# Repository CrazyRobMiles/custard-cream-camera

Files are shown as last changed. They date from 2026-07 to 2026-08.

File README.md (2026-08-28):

# Custard Cream Camera

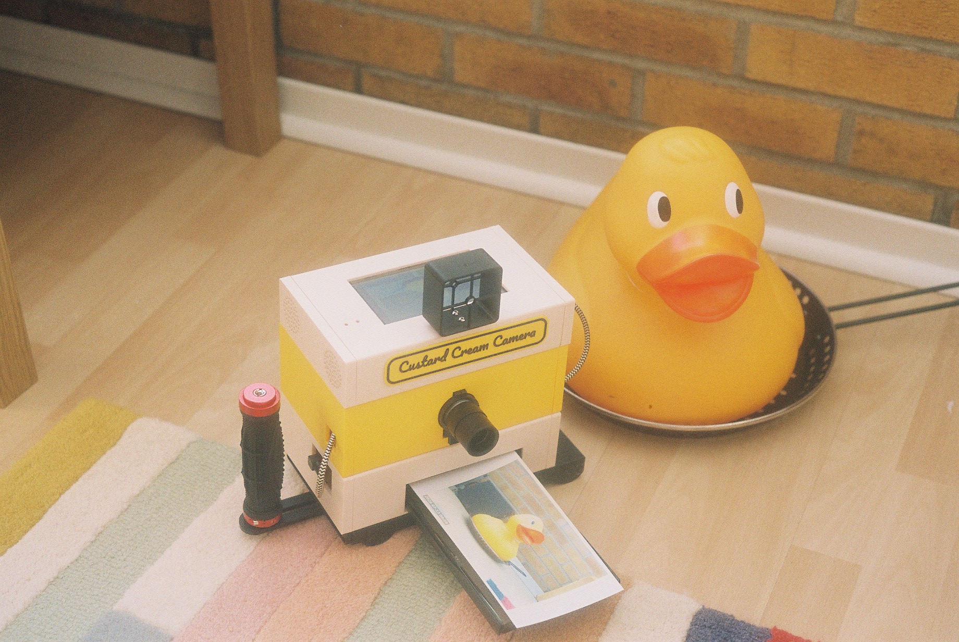
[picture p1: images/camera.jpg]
Image of the camera and a large rubber duck


A camera-and-photo-review appliance for a small touchscreen Raspberry Pi build. Takes pictures (or receives them over FTP from a real camera), lets you review, print, publish, and voice-edit them with AI - and print them on a built-in printer. It can also publish pictures to Flickr, Bluesky, and a self-hosted Custard Cream Camera Server — pick which one from a menu on the Publish button.

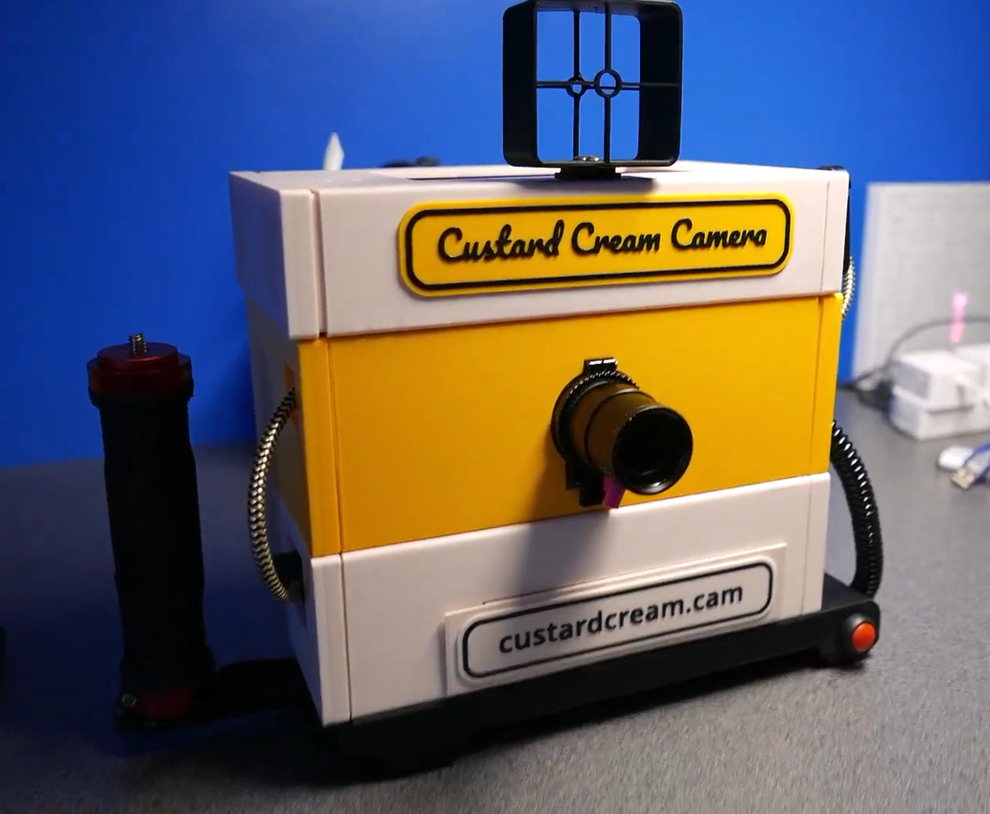
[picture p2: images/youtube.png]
YouTube Screenshot (https://youtu.be/TUCZbDL9_Vs)


To find out more about the camera click on the image above to see a short video.

## Camera configuration

You can use the camera as a camera, or you can use it as an FTP server which other cameras can connect to. All the image storage, processing and printing features are available in this mode. If you are not sure what any of this means, use it in camera mode. 

`settings.json`'s top-level `"mode"` key picks the home screen:

* **`"mode": "camera"`** — a live viewfinder with **Capture**/**Play** modes: take a photo with the on-screen button, a Bluetooth/wired shutter remote, or the keyboard spacebar.
* **`"mode": "ftp"`** — no camera: this device receives JPEGs over FTP (e.g. from a Sony camera's FTP-transfer feature) and is always in Play mode, showing the newest arrival first.
* **`"mode": "camera_ftp"`** — both at once: the live viewfinder/Capture-Play flow of `"camera"` mode, plus the FTP receiver of `"ftp"` mode running in the background. A photo arriving over FTP jumps to the front and interrupts Capture/Play immediately, the same way it does in plain `"ftp"` mode.

Either way, reviewing, printing, publishing, and voice-editing photos already in `captures/` is exactly the same code and behavior — see [Home Screen: Camera Mode vs FTP Mode](docs/home-screen-modes.md).

Inspired by the camera made by [Nikbuild](https://github.com/nickbild/banamera)

## Getting Started

**New device, nothing set up yet?** Follow [Setting Up From Scratch](docs/setup-guide.md) — a
single ordered walkthrough from a bare Raspberry Pi OS install to a running camera, covering system
packages, the venv, `settings.json`, API keys, and every optional feature, in the order you'd
actually do them. Start there rather than the reference list below.

## Reference

Once a device is set up, these cover each feature in more depth than the walkthrough above —
useful when you want to change how something already-configured behaves, or when troubleshooting
something specific.

**Core:**

* [Setting Up the Python Virtual Environment](docs/venv-setup.md) — create, activate, and (if needed) recreate the `venv` this app always runs inside; what differs between camera mode and FTP mode.
* [Running the App](docs/running-the-app.md) — start it from a terminal, or launch it from a desktop icon with no keyboard needed.
* [Storing API Keys on the Device](docs/api-keys.md) — get the Gemini/Flickr/Bluesky/server keys set automatically on every launch, without committing them to git.
* [Display Backends](docs/display-backends.md) — pick between an HDMI touchscreen or a native HDMI display, and configure it in `settings.json`.
* [Home Screen: Camera Mode vs FTP Mode](docs/home-screen-modes.md) — the live viewfinder vs. reviewing FTP-received photos; reviewing/printing/speaking/publishing existing photos works the same either way.

**Camera mode:**

* [Camera Orientation](docs/camera-orientation.md) — fix an upside-down or mirrored viewfinder with `hflip`/`vflip`.
* [Exposure Compensation](docs/exposure-compensation.md) — bias the auto-exposure with on-screen EV+/EV- buttons for backlit or overexposed scenes.
* [Shutter Remotes](docs/shutter-remote.md) — trigger photos and voice edits from a Bluetooth or wired USB-serial remote instead of the touchscreen; either or both can be enabled at once.
* [Audio Output (Shutter Sound)](docs/audio-output.md) — a click sound plays when a photo is taken, configurable and safe to enable even with no audio hardware present.

**FTP mode (and `camera_ftp`):**

* [Receiving Photos over FTP](docs/ftp-setup.md) — configuring the sending camera's FTP-transfer feature to talk to this app, and how uploads get turned into previewable photos.

**Either mode:**

* [Voice-Prompted AI Edits](docs/voice-ai-edits.md) — record a spoken instruction and have Gemini edit the photo.
* [Printing](docs/printing.md) — send photos to CUPS, test the pipeline without wasting paper, and add a watermark/date stamp.
* [Publishing to Flickr](docs/publishing-flickr.md) — one-time OAuth setup, then upload photos straight from the app.
* [Publishing to Bluesky](docs/publishing-bsky.md) — post photos with an app password, no OAuth needed.

**Hardware:**

* [Canon SELPHY CP400 + CUPS](docs/printer-cups-setup.md) — get a CP400 dye-sublimation printer working with CUPS and Gutenprint on Raspberry Pi OS.

## 3D-Printed Case

STL files for the camera's enclosure are in [case/](case/) — print them and snap/screw the lids onto their matching bases:

* **Controller** — `ControllerBase.stl` with `ControllerLid.stl`, `ControllerLeftLid.stl`, and `ControllerSpeakerLid.stl` (vented for the speaker).
* **Battery** — `BatteryBase.stl` with `BatteryLidLeft.stl` and `BatteryLidRight.stl`, plus `batteryHolderLid.stl`.
* **Printer** — `PrinterBase.stl` with `PrinterLidLeft.stl` and `PrinterLidRight.stl`, housing the SELPHY CP400.
* **Handle** — `HandleBase.stl` with `HandleBaseLid.stl`.
* **Paper** — `paperLid.stl` covers the printer's paper tray.

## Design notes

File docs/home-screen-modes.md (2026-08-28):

# Home Screen: Camera Mode vs FTP Mode

`settings.json`'s top-level `"mode"` key (`"camera"`, `"ftp"`, or `"camera_ftp"`) picks which home
screen this app shows. Everything else — reviewing, printing, publishing, and voice-editing photos
already in `captures/` — works identically across all three; only how photos *arrive* differs.

## Camera mode (`"mode": "camera"`)

Live viewfinder with a **Capture** and **Play** mode.

### Capture mode

The default mode: a live viewfinder with **Click** (take a photo) and **Play** (switch to Play
mode) buttons, plus the [exposure compensation](exposure-compensation.md) EV-/EV+ buttons in the
top corners.

### Play mode

Reviews and acts on photos already in `captures/`, one at a time, full screen:

* **Capture** — back to Capture mode (the live viewfinder), without taking a photo.
* **Print** / **Speak or AI Edit** / **Publish** — act immediately on whichever photo is currently
  shown, no separate "choose, then act" step. The AI-edit button's behavior depends on
  `"ai_edit"` in settings.json: by default (`"input_method": "voice"`) it's **Speak**, hold-to-talk
  — press to record an editing instruction, release to send it; with `"input_method": "keyboard"`
  it's **AI Edit**, a normal tap that opens a grid of preset prompts plus a custom on-screen-keyboard
  option instead. Setting `"ai_edit.enabled"` to `false` removes this button entirely. **Publish**
  opens a menu of every *enabled* destination (Flickr, Bluesky, Custard Cream Server, ...) — tap one
  to send this photo there and return here, with a "Published to \<name\>!" confirmation naming
  which one; publishing to more than one destination means pressing **Publish** again afterwards and
  picking another. If only one destination is enabled, Publish skips the menu and sends straight to
  it. See [Voice-Prompted AI Edits](voice-ai-edits.md), [Printing](printing.md), and
  [Publishing to Flickr](publishing-flickr.md) for what each of those actually does.
* **`<`** / **`>`** (small buttons on the left/right screen edges) — step to the previous/next
  photo one at a time, newest-first.
* **Page** (top-right corner) — opens a 3×3 grid of the current page of 9 photos; tapping a
  thumbnail makes it the current selection and returns to the single-photo view. **Left**/**Right**
  in the grid page through older/newer groups of 9; **Back** returns to the single-photo view
  without changing the selection.
* **Stop** (top-left corner) — exits the app cleanly. This is the only on-screen way to quit, for
  when it's launched from the [desktop icon](running-the-app.md) with no keyboard or window chrome
  available.

Entering Play mode (via the **Play** button, from anywhere) always lands on the most recently taken
photo - it re-scans `captures/` fresh each time rather than remembering a stale position from last
visit. An AI edit or a fresh **Click** while reviewing similarly become the new current selection,
the same as if you'd just taken them.

There's no on-screen quit button in Capture mode — switch to Play mode and use **Stop**, or press
keyboard `q` in the terminal, or (on the HDMI backends) Escape / close the window.

### The physical shutter remote and keyboard spacebar

The [Bluetooth shutter remote](shutter-remote.md)'s photo key and the keyboard spacebar behave
differently depending on mode:

* In **Capture mode**, they take a photo immediately, same as **Click**.
* In **Play mode**, they switch back to Capture mode *without* taking a photo — pressing the
  physical shutter while reviewing old photos shouldn't blindly capture whatever the camera happens
  to be pointed at; it just gets you back to the viewfinder to compose deliberately.

The remote's speak key is unaffected by mode — it always bypasses Play mode entirely and acts
immediately on a fresh capture, since requiring on-screen navigation would defeat the point of a
physical, look-free trigger.

## FTP mode (`"mode": "ftp"`)

There's no camera, so there's no Capture mode to switch away from - this is always Play mode. The
app starts on a "Waiting for photos..." placeholder and shows the most recent photo full-screen as
soon as one arrives (see [Receiving Photos over FTP](ftp-setup.md)):

* **Print** / **Speak** / **Publish** / **`<`** / **`>`** / **Page** / **Stop** — same buttons and
  behavior as camera mode's Play mode above, just with no **Capture** button (there's no other mode
  to switch to).

### When a new photo arrives

A newly-received photo always jumps to the front and becomes the current selection - the same way a
fresh AI edit does. If it arrives while you're stepping through older photos, or while a
Publish/Print/AI-edit is quietly working in the background, it interrupts that and shows the new
one right away (any publish/print/edit already in flight keeps working on the photo it started with
- only the screen moves on). If it arrives while a full-screen banner or review/keyboard screen has
temporarily taken over (a "Published!"/print-result banner, the QR-code screen, or the
Send/Reject/Edit review from [Voice-Prompted AI Edits](voice-ai-edits.md)), it's picked up as soon
as that screen closes rather than interrupting it mid-way.

Restarting the app rescans `captures/` for anything already there (e.g. left over from before a
restart) and shows the newest, the same as the first-arrival case.

There's no live viewfinder, no exposure compensation, and no shutter button in this mode - it never
takes a photo itself, only receives ones already taken.

## Camera + FTP mode (`"mode": "camera_ftp"`)

Both of the above at once: the live viewfinder and Capture/Play flow from Camera mode, plus the FTP
receiver from FTP mode running in the background the whole time - see
[Receiving Photos over FTP](ftp-setup.md) for configuring the sending camera's side. The app starts
in Capture mode, same as plain Camera mode.

A photo arriving over FTP behaves exactly as described in
[When a new photo arrives](#when-a-new-photo-arrives) above - it jumps to the front and interrupts
whatever's on screen (Capture mode's live viewfinder included), the same way it would in plain FTP
mode. The live viewfinder itself keeps running in the background while that photo is shown; press
**Capture** to go back to it.

This is useful when you want the device's own camera and an external camera's FTP-transfer feature
(e.g. a Sony body) both feeding the same `captures/` folder and review flow, rather than choosing
one or the other.

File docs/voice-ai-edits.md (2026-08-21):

# Voice-Prompted AI Edits

How you provide the editing instruction is controlled by `"input_method"` under `"ai_edit"` in
[settings.json](../settings.json.example) — `"voice"` (the default, described first below) or
`"keyboard"` (preset prompts plus a custom on-screen keyboard entry, see
[Keyboard/Preset Input](#keyboardpreset-input) further down). Setting `"ai_edit.enabled"` to
`false` removes AI editing entirely — no button in Play mode, and (camera mode) no shutter-remote
speak-key binding either — useful for a device that only needs to receive/print/publish photos,
e.g. a low-spec Pi Zero-class image receiver.

## Voice input (`ai_edit.input_method`: `"voice"`, the default)

In Play mode (see [Home Screen: Camera Mode vs FTP Mode](home-screen-modes.md)), hold **Speak** (or, in camera mode, use the shutter remote's speak key, which works from any mode), say an editing instruction (e.g. "make it look like a watercolor painting"), and release. The app transcribes what you said, then shows you the transcript with three options before anything is sent anywhere for editing:

* **Send** — sends it, with the currently displayed image, to Google's Gemini ("Nano Banana") image model for editing.
* **Reject** — discards it. Nothing is sent for editing; you're back where you started.
* **Edit** — opens an on-screen keyboard to correct the text (misheard words, added detail, etc.), then returns to this same Send/Reject/Edit screen with the corrected text.

This review step exists because speech recognition isn't perfect, and a misheard instruction sent straight to an image-editing model wastes a request (and, depending on your Gemini plan, a quota unit) on a result you never wanted. Once sent, the result is saved to `captures/` as `ai_<timestamp>.jpg`, shown on screen for a few seconds, and becomes the new current selection. Image editing always goes through Gemini; the app stays responsive while it's working since the network calls run on a background thread.

Transcription (turning your speech into the text prompt) is a **pluggable backend**, selected via `"transcribe_provider"` under `"custard_cream"` in [settings.json](../settings.json.example) — this setting only matters when `"ai_edit.input_method"` is `"voice"`:

- **`"vosk"` (the shipped default)** — runs entirely on the device via a local [Vosk](https://alphacephei.com/vosk/) model, no network round-trip. Since it recognises speech live, the transcript is displayed on screen as you talk, updating word by word while **Speak** is still held. Implemented in [lib/transcription/vosk_transcriber.py](../lib/transcription/vosk_transcriber.py).
- **`"gemini"`** — sends the whole recording to Gemini once you release **Speak**. No live text — just the "Recording... release to send" banner until it's done. Implemented in [lib/transcription/gemini_transcriber.py](../lib/transcription/gemini_transcriber.py).

Both backends implement the same interface ([lib/transcription/base.py](../lib/transcription/base.py)), selected by [lib/transcription/__init__.py](../lib/transcription/__init__.py)'s `create_transcriber()` — the same plugin pattern used for [publishers](../lib/publishers/) and [displays](../lib/displays/). Image editing itself is unaffected by this choice and stays in [lib/NanoBananaClient.py](../lib/NanoBananaClient.py). The whole flow (`start_voice_prompt()`/`finish_voice_prompt()`/`review_ai_prompt()`/`run_ai_edit()`/...) lives in [custard_cream_camera.py](../custard_cream_camera.py) — the fresh-capture branch it falls back to only matters in camera mode, since an FTP-mode device never captures a photo itself.

On a lower-powered device (e.g. a Pi Zero W 2 running in FTP mode), consider `"vosk"` over `"gemini"` for transcription if the network connection is unreliable, since it needs no round-trip at all - though the image-edit step itself always needs Gemini regardless.

## Keyboard/Preset Input

Set `"ai_edit.input_method"` to `"keyboard"` for a device with no microphone, or where speech
recognition simply isn't wanted (e.g. a low-spec Pi Zero-class image receiver/printer, where a
local Vosk model is too much for the hardware - see below). The Play-mode button becomes **AI
Edit** (a normal tap, not hold-to-talk) instead of **Speak**:

* Tapping it shows a grid of the prompts configured under `"ai_edit.presets"` in settings.json (any
  number, not just four - laid out two per row), plus **Custom...** and **Back**.
* Picking a preset, or **Custom...** (which opens the same on-screen keyboard **Edit** uses in the
  voice flow above, starting blank), lands on the same Send/Reject/Edit confirm screen described
  above - so a preset or typed prompt can still be tweaked or rejected before it's sent to Gemini.
* **Back** returns to Play mode without choosing anything.

Crucially, no transcriber is created at all in this mode (nor when `"ai_edit.enabled"` is
`false`): `"transcribe_provider"`/`"vosk"` in settings.json are simply not read, the `vosk` package
is never imported, and no Vosk model is loaded into memory - important on something like a Pi Zero,
where even a "small" ~40MB model is a real cost you don't want to pay if voice input is never used.
In camera mode, the shutter remote's speak key is also left unbound in this case, since it exists
purely to drive hold-to-talk.

## Setup

Steps 1 and 3 (the Gemini API key) apply regardless of `"ai_edit.input_method"`, since image
editing always goes through Gemini. Steps 2, 4, and 5 only matter for `"input_method": "voice"` —
skip them entirely for `"keyboard"` (or `"ai_edit.enabled": false`).

1. **Get a Gemini API key.** Go to [aistudio.google.com/apikey](https://aistudio.google.com/apikey), sign in with a Google account, and create a key. This is needed for image editing regardless of transcription backend, and for transcription itself if you use `"gemini"`.

2. **Make sure the SDKs are installed.** `google-genai` is already in [requirements.txt](../requirements.txt), pulled in by the normal `pip install -r requirements.txt` venv setup. `vosk` is kept in its own [requirements-vosk.txt](../requirements-vosk.txt) instead (see [Setting Up the Python Virtual Environment](venv-setup.md)), since it's a real install/memory cost not worth paying on a device that never uses voice input — install it with `pip install -r requirements-vosk.txt` if you're using `"vosk"` as the provider.

3. **Set the API key as an environment variable.** `NanoBananaClient.py` reads it from `GOOGLE_API_KEY` by default (the variable name is itself configurable via `"api_key_env"` under `"custard_cream"` in settings.json) — deliberately *not* stored in `settings.json`, since that file is checked into git. For a quick one-off test from a terminal:
   ```bash
   export GOOGLE_API_KEY="your-api-key"
   ```
   For it to be set automatically every time the app runs (including from the desktop icon, with no terminal involved) see [Storing API Keys on the Device](api-keys.md).

4. **If using Vosk, download a model.** See [Installing Vosk](venv-setup.md#installing-vosk-local-speech-recognition) for the exact download/unzip commands and a one-liner to verify it loads. The default settings expect `vosk-model-small-en-us-0.15` (~40MB) unzipped to `models/vosk-model-small-en-us-0.15`, matching `"custard_cream.vosk.model_path"` in settings.json — adjust that setting if you use a different model or location. **This is loaded once at app startup** (not on first Speak press, to avoid a delay on first use) — a missing or wrong `model_path` will fail app startup entirely, not just the Speak feature, so get this right before relying on Vosk as the active provider.

5. **Check the microphone.** Both backends need `arecord` (part of `alsa-utils`, normally already installed on Raspberry Pi OS — `sudo apt install alsa-utils` if not). Confirm it works standalone first:
   ```bash
   arecord -f S16_LE -r 16000 -c 1 -d 3 test.wav && aplay test.wav
   ```
   If you have multiple audio devices, set `"device"` under `"custard_cream"` in settings.json to the right ALSA device name (`arecord -l` lists them) — it's `null` by default, which uses the system default input. This is shared by both transcription backends, since it's a property of the physical mic, not the transcriber.

6. **Test it.** Play mode has no option to take a fresh photo, so make sure at least one photo exists first — in camera mode, press **Click** (in Capture mode); in FTP mode, [receive a photo over FTP](ftp-setup.md). Then: hold **Speak**, say something like "make it look like a watercolor painting" (if using Vosk, watch the recognised text build up on screen as you talk), and release. The edited image should then appear on screen and save to `captures/ai_<timestamp>.jpg`.

Recording length and the result's on-screen hold time are also configurable under `"custard_cream"` in settings.json. The Gemini model IDs (`transcribe_model`, `edit_model`) may need adjusting as Google's model naming evolves — check the current names in the [Gemini API docs](https://ai.google.dev/gemini-api/docs/models) if editing (or Gemini-backend transcription) fails with a "model not found" style error.

## Diagnostics

Progress is shown on screen as well as logged. While a request is in flight, the banner that would otherwise just say "Processing..." instead shows what's actually happening: "Transcribing...", then (once you've reviewed and sent the prompt) "Sending image for processing...", then "Received result, saving..." — the same on-screen-diagnostics idea used for [printing](printing.md), applied to this workflow.

Every stage also prints a `Speak: ...` line to the terminal (or `custard_cream_camera.log`), so a stuck or failed edit can be narrowed down to exactly where it stopped: recording start/stop, transcription (whichever backend is active) and its result, whether the prompt was sent/rejected at the review step, the request sent for image editing, and the response received (including any text the model returned instead of an image, e.g. a safety refusal — normally invisible on screen, since the caller only ever sees `None`).

Requests to Gemini time out after `"timeout_seconds"` (default `30`) under `"custard_cream"` in settings.json — without this, a stalled connection (flaky wifi, a network path that silently drops packets) would hang indefinitely with no error and no diagnostic output at all. This only applies to work that actually goes over the network: image editing always, and transcription only when `"transcribe_provider"` is `"gemini"` — Vosk transcription is local and isn't affected by connectivity at all. If a Gemini-backed request hangs repeatedly even with a normally-reliable connection, try raising `"timeout_seconds"` in case it's just Gemini being slow rather than the connection actually stalling.

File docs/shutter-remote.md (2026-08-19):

# Shutter Remotes

The app supports three independent physical shutter remotes — a Bluetooth one, a wired USB-serial one, and a plain GPIO push-button — each with its own `"enabled"` flag in [settings.json](../settings.json.example), so any or all can be active at once.

## Bluetooth Shutter Remote

Cheap Bluetooth camera remotes don't have a real "pairing mode" — they just have two buttons/positions (labelled iOS/Android or similar) that each send a different key, since iOS and Android camera apps historically listened for different shortcuts. [shutter_remote.py](../shutter_remote.py) listens for both directly at the input-device level (via `evdev`), independent of which window has focus:

* **iOS** button → Volume Up (`KEY_VOLUMEUP`) → takes a photo in [Capture mode](home-screen-modes.md), the same action as the **Click** button - or, if you're currently in Play mode reviewing photos, switches back to Capture mode without taking a photo.
* **Android** button → Enter (`KEY_ENTER`) → hold-to-talk, the same as **Play** mode's **Speak** button: pressing starts recording, releasing sends it. Unlike the photo key, this works from any mode - it always acts on a fresh capture, bypassing Play mode entirely. This relies on the remote sending a genuine press-then-release pair for a physical hold, which is normal HID keyboard behavior, but worth confirming for your specific unit (see below).

To enable it:

1. Set `"shutter_remote": {"enabled": true}` in [settings.json](../settings.json.example).
2. Make sure your user can read input devices: `sudo usermod -aG input $USER`, then log out and back in (or reboot) for group membership to take effect.

The Volume Up mapping is easy to confirm: pressing the iOS button should show your desktop's volume OSD. The Enter mapping is a best guess for "Android mode" on these remotes — if it doesn't trigger recording, confirm the actual key it sends (see below), and set `"photo_key"`/`"speak_key"` in `settings.json` to match (either can be set to `null` to disable that mapping without disabling the other).

### Automatic device discovery

`"device_name"` normally doesn't need to be set at all. `shutter_remote.py` already knows exactly which keys it cares about (`photo_key`/`speak_key`), so with `"device_name": null` it auto-selects any connected input device that reports supporting one of those keys — asking each device "can you send `KEY_VOLUMEUP`/`KEY_ENTER`?" rather than needing to be told a product name up front. This is also what makes `"grab": true` safe by default: it can only ever grab a device that actually reports one of those two keys, never your touchscreen, mouse, or keyboard, since none of those report `KEY_VOLUMEUP`/`KEY_ENTER` as a capability.

Startup then prints just the auto-selected devices, e.g.:
```
ShutterRemote: listening on AB Shutter3        Keyboard, AB Shutter3        Consumer Control
```
Bluetooth "combo" remotes like this commonly register as *two* separate logical devices, since Enter and Volume Up/Down live on different HID pages (`Keyboard` vs `Consumer Control`) — both get auto-selected independently since each reports one of the two keys.

**Caveat:** capability matching can occasionally over-match — e.g. many USB audio adapters/microphones expose a "media control" HID interface reporting `KEY_VOLUMEUP`/`KEY_VOLUMEDOWN`/`KEY_MUTE` even without physical buttons, purely as part of the USB Audio Class spec, so one could get auto-selected too (and grabbed, if `"grab": true"`, though this shouldn't affect its actual audio capture - that's a separate USB interface). Usually harmless, since it'd only matter if that device ever emits a real `KEY_VOLUMEUP` event, but if something unrelated seems to be triggering captures, or you'd rather target the remote precisely, set `"device_name"` to its name (visible in the startup log above, or via `evtest`) to bypass capability matching entirely for an explicit name match instead:
```bash
sudo apt install evtest
sudo evtest   # pick your remote from the list, press a button, read the KEY_ name and device name
```

**Not being detected?** `shutter_remote.py` retries device discovery every second (Bluetooth remotes routinely disconnect between presses to save battery, and may not even be connected yet when the app starts), so it should pick the remote up on its own within a second or two of it reconnecting. If it still doesn't, try power-cycling the remote — a stale/half-open Bluetooth connection from a previous session is a common cause and a fresh reconnect usually clears it.

**Was working, then stopped reconnecting entirely?** `shutter_remote.py` only watches for input devices the OS has already connected — it doesn't drive Bluetooth pairing/reconnection itself, so if `bluetoothd` stops auto-reconnecting to the remote, there's nothing for it to find no matter how long it retries. Check:
```bash
bluetoothctl devices          # find the remote's MAC address
bluetoothctl info <MAC>       # check Paired/Connected/Trusted
```
If `Paired: yes` but `Connected: no`, and `Trusted: no`, that's very likely the cause — an untrusted paired device doesn't get automatically reconnected by `bluetoothd` the same way a trusted one does, so once it disconnects (its normal power-saving behavior) it just stays disconnected until something explicitly reconnects it. Fix it with:
```bash
bluetoothctl trust <MAC>
```
which should make it reconnect immediately and keep auto-reconnecting from then on.

## Wired (USB Serial) Shutter Remote

For a simple homemade remote connected over USB serial and sending the word `click` (newline-terminated) each time its button is pressed. Implemented in [serial_shutter_remote.py](../serial_shutter_remote.py), it's much simpler than the Bluetooth remote above: one button, one action - it always takes a photo (the same event as the Bluetooth remote's `photo_key`), the same as pressing **Click** in Capture mode or, if you're currently in Play mode, switching back to Capture mode without taking a photo. It doesn't have a Speak/hold-to-talk equivalent.

To enable it:

1. Plug the remote in and find its device path: `ls /dev/ttyUSB* /dev/ttyACM*` (USB-serial adapters usually show up as one or the other, depending on the chip they use).
2. Set `"serial_remote"` in [settings.json](../settings.json.example):
   ```json
   "serial_remote": {
       "enabled": true,
       "port": "/dev/ttyUSB0",
       "baud_rate": 9600
   }
   ```
   `"baud_rate"` must match whatever the remote's firmware is actually configured to send at - 9600 is a common default, but check your specific device.
3. Make sure your user can access serial ports: `sudo usermod -aG dialout $USER`, then log out and back in (or reboot) for group membership to take effect.

This remote and the other two are fully independent - any combination can be `"enabled": true` at once, each triggering the same photo action.

**Not being detected / nothing happens on click?** Like the Bluetooth remote, `serial_shutter_remote.py` retries opening the port every second if it's missing (unplugged, not yet enumerated at boot), so it should pick the remote up within a second or two of being plugged in - check the console/log for a `SerialShutterRemote: listening on ...` line to confirm it connected. If it connects but clicks don't register, confirm what the remote is actually sending, e.g.:
```bash
screen /dev/ttyUSB0 9600
```
(press the remote's button and confirm you see `click` printed; `Ctrl-A` `k` `y` to exit `screen`) - a mismatched baud rate typically shows up as garbled text rather than silence.

## GPIO Shutter Remote

For a switch wired directly to a GPIO pin on the Pi - no microcontroller/USB adapter needed. Implemented in [gpio_shutter_remote.py](../gpio_shutter_remote.py) using [gpiozero](https://gpiozero.readthedocs.io/), which handles debouncing itself, so the wiring can be as simple as a switch between the GPIO pin and ground.

Like the serial remote, it's one button, one action - it always takes a photo, the same as pressing **Click** in Capture mode or, if you're currently in Play mode, switching back to Capture mode without taking a photo.

To enable it, set `"gpio_remote"` in [settings.json](../settings.json.example):
```json
"gpio_remote": {
    "enabled": true,
    "pin": 26,
    "active_low": true
}
```
* `"pin"` is the BCM GPIO number (not the physical header pin number) the switch is wired to.
* `"active_low"` should be `true` if the switch connects the pin to ground when pressed (the pin idles high via the Pi's internal pull-up resistor, and reads low when pressed) - this is the simplest wiring, needing nothing but a switch and two wires. Set it to `false` if the switch instead connects the pin to 3.3V when pressed (the pin idles low via the Pi's internal pull-down resistor, and reads high when pressed).

This remote and the other two are fully independent - any combination can be `"enabled": true` at once, each triggering the same photo action.

**Nothing happens on press?** Check the console/log for a `GpioShutterRemote: listening on GPIO<pin> (active low/high)` line at startup to confirm the pin opened - if it prints a "could not open" error instead, another process may already be using that pin, or the pin number may not exist on your Pi model. If it opened fine but presses don't register, double check `"active_low"` matches your wiring - a switch wired to ground with `"active_low": false` (or vice versa) will just look like the button is permanently held (or never pressed) rather than causing an obvious error.

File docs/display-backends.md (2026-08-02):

# Display Backends

`custard_cream_camera.py` renders through a pluggable display layer in [lib/displays/](../lib/displays/). One backend is provided, for devices with a native HDMI display — a SPI panel backend (`ili9486`) used to be supported but was dropped: its framerate was too low to manually focus the camera image, making it non-viable as a platform regardless of anything else. A dedicated fullscreen SDL/pygame backend (`hdmi-pygame`) was also dropped: `hdmi-desktop` turned out to be fast enough on its own, so there was no need to carry the extra SDL video-driver dependency and setup burden.

* `hdmi-desktop` — a plain window via Tkinter, using the mouse for touch input ([lib/displays/hdmi_desktop_display.py](../lib/displays/hdmi_desktop_display.py)). No fullscreen mode-switching or video driver selection — it just opens an ordinary window through whatever windowing system the desktop is already using, the same as any other desktop app.

Select the backend and tune its options in [settings.json](../settings.json.example):

```json
{
    "display": {
        "type": "hdmi-desktop",
        "width": 800,
        "height": 480
    }
}
```

`hdmi-desktop` needs Tkinter, which on Raspberry Pi OS / Debian is a system package, not a pip one:

```bash
sudo apt install python3-tk
```

## `width`/`height` — the logical canvas size

Every screen (menus, the viewfinder or current photo, the on-screen keyboard) is drawn against a logical canvas of `width` x `height`, then scaled up to fill whatever the real window/output size is. Defaults to `480`x`320` if omitted, matching the size this app originally shipped with.

A bigger canvas gives more room for on-screen text and controls (e.g. the AI-prompt keyboard, see [Voice-Prompted AI Edits](voice-ai-edits.md)) at the cost of more pixels to draw per frame - worth watching on a lower-powered device (e.g. a Pi Zero W 2), which has much less headroom than a full-size Pi. If a larger size causes worse frame rates on your hardware, drop `width`/`height` back down (or remove them entirely to fall back to `480`x`320`) — no code change needed either way. Every layout in the app computes itself from these values at runtime rather than assuming a fixed size, so any resolution should work.

## `DISPLAY`/`XDG_RUNTIME_DIR` not set

Both HDMI backends need `DISPLAY` (and ideally `XDG_RUNTIME_DIR`) set to reach the desktop session — normally automatic when logged into the Pi's own desktop, but **not** when launched from a plain SSH shell or a remote-dev tool's integrated terminal (e.g. VS Code Remote-SSH), which don't inherit those variables. Activating the Python venv doesn't set them either (it only touches `PATH`), so this can bite regardless of venv use.

`lib/displays/__init__.py` fills in a best-effort default for either one if it's missing — it looks for a real X11 socket under `/tmp/.X11-unix` and a real `/run/user/<uid>` directory, and only sets the variable if it finds one (it won't invent a display that doesn't actually exist), printing what it defaulted to. This should cover the common case of a single desktop session on `:0` without you needing to `export` anything by hand. If it still can't find one — e.g. no desktop session is running at all — the underlying error will still surface, since at that point there's genuinely nothing to connect to.

## Touch/clicks stop responding, but the cursor still moves

If the touchscreen (or mouse) can move the cursor around but clicks don't register anywhere, the likely cause is a modal dialog left open somewhere behind the app, silently eating every click because it's waiting for you to click its own OK/Cancel first. This is easy to miss since the app is fullscreen and the dialog is hidden underneath it.

The known trigger is the one-time Flickr `setup_flickr_auth.py` script (see [Publishing to Flickr](publishing-flickr.md)): if a browser is opened directly on the Pi's own desktop for the OAuth step, it can prompt for a keyring/password dialog to store the saved login, and that dialog stays open — and stays modal — even after the browser flow is done. Dismissing it (even indirectly, e.g. by unplugging a keyboard that happened to also close it) immediately restores clicking. Nothing this app itself does should pop up a dialog, so as long as the desktop is clean before launching it, this shouldn't come up — but if clicks ever mysteriously stop working, check for a stray dialog window before assuming it's a display/touch driver problem.

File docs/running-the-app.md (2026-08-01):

# Running the App

## From a Terminal

Once the virtual environment has been activated:

```bash
python custard_cream_camera.py
```

## From a Desktop Icon

[run_custard_cream_camera.sh](../run_custard_cream_camera.sh) and [custard-cream-camera.desktop](../custard-cream-camera.desktop) let you launch the app by double-clicking an icon instead of typing commands in a terminal. The script finds its own location automatically and activates `venv` if one exists next to it. `custard-cream-camera.desktop` ships with `Terminal=false`, so no terminal window appears — if `custard_cream_camera.py` exits with an error, the output goes to `custard_cream_camera.log` next to the script instead of a window you'd need a keyboard to dismiss. Set `Terminal=true` if you'd rather see a terminal window on launch (it will then keep it open on error so you can read what went wrong, instead of logging to a file).

To install it:

1. Edit `Exec=` in `custard-cream-camera.desktop` if this repo isn't cloned at `/home/rob/custard-cream-camera`.
2. Copy the `.desktop` file to your desktop and/or application menu:
   ```bash
   cp custard-cream-camera.desktop ~/Desktop/
   cp custard-cream-camera.desktop ~/.local/share/applications/   # to also show it in the app menu
   ```
3. Make sure both `run_custard_cream_camera.sh` and the `.desktop` file are executable — git doesn't reliably preserve the executable bit across clones, so a fresh clone can silently lack it, which shows up as the icon failing to launch (PCManFM reports this as "Invalid desktop entry file", which is misleading — the underlying cause is `Permission denied` running the script):
   ```bash
   chmod +x ~/custard-cream-camera/run_custard_cream_camera.sh
   chmod +x ~/Desktop/custard-cream-camera.desktop
   ```
   Most file managers also treat a newly-placed `.desktop` file as untrusted the first time — right-click the icon and choose "Allow Launching" / "Trust" (wording varies by desktop environment).
   On Raspberry Pi OS's default file manager, PCManFM, double-clicking instead pops up an "Execute / Execute in Terminal / Open / Cancel" menu every time, even once the file is executable - this isn't the same "untrusted" mechanism GNOME/Nautilus uses (so `gio set metadata::trusted` has no effect here), it's a PCManFM-only setting. Fix it via **File Manager → Edit → Preferences → General → "Don't ask options on launch executable file"**. This writes `quick_exec=1` to PCManFM's own config file - editing that file directly isn't a reliable alternative, since it may not exist yet until PCManFM has been opened/configured at least once. Note this is a global toggle: it suppresses the confirmation for any executable double-clicked on the desktop, not just this icon.

## What you'll see on launch

Depends on `settings.json`'s `"mode"` — see [Home Screen: Camera Mode vs FTP Mode](home-screen-modes.md):

* **Camera mode** — a live viewfinder with **Click**/**Play** buttons.
* **FTP mode** — no camera, so no viewfinder: it starts on a "Waiting for photos..." placeholder and switches to showing the newest received photo as soon as one arrives over FTP. See [Receiving Photos over FTP](ftp-setup.md) for configuring the camera side.

## A browser/keyring password dialog appears when the app closes

`custard_cream_camera.py` never opens a browser itself - if one appears (often along with a prompt to unlock/create a login keyring) right as the app exits, it's almost always a leftover browser window from the one-time `setup_flickr_auth.py` step (see [Publishing to Flickr](publishing-flickr.md)), still sitting open behind the fullscreen app the whole time it was running. Closing the app's fullscreen window just reveals what was underneath, it isn't spawning anything new.

Close the stray browser (`pkill chromium`, or whatever browser you used) to clear it. To stop it happening again:

* Run `setup_flickr_auth.py`'s browser step on a different device (phone, laptop) rather than this Pi's own desktop, and close that browser window once you've pasted the verification code back into the terminal.
* If you don't want passwords persisted on the Pi at all, turn off Chromium's password saving so it has nothing to ask the keyring to store: address bar → `chrome://settings/passwords` → toggle off **"Offer to save passwords"** (or via the **⋮** menu → Settings → Autofill and passwords → Password Manager if typing the URL doesn't work). You can also launch Chromium with `--password-store=basic` to bypass the OS keyring entirely.

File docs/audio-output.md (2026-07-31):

# Audio Output (Shutter Sound)

Taking a photo (via the **Click** button, the [shutter remote](shutter-remote.md), or the spacebar) plays a short click sound in addition to the white screen flash, via `aplay`. This is implemented as a fire-and-forget call in `play_sound()` in [custard_cream_camera.py](../custard_cream_camera.py) - it never blocks on the sound finishing, and never raises if playback fails, so a missing or misconfigured audio device just means silence instead of a broken shutter button. This makes it safe to leave enabled even on a device with no audio hardware at all.

Configurable under `"audio_output"` in [settings.json](../settings.json.example):

```json
"audio_output": {
    "enabled": true,
    "device": null,
    "shutter_sound": "assets/audio/shutter.wav"
}
```

* `"enabled"` — set `false` to disable the sound entirely (the screen flash still happens either way).
* `"device"` — an explicit ALSA device string (e.g. `"plughw:3,0"`), passed to `aplay -D`. Leave `null` to use ALSA's `default` device.
* `"shutter_sound"` — path to a `.wav` file, relative to the repo root. The one shipped in [assets/audio/](../assets/audio/) is a short synthesized click generated with Python's stdlib `wave` module (not a real recording) - swap in your own `.wav` file here if you'd like a different sound.

## Finding the right output device

```bash
aplay -L
```
lists everything ALSA can currently see. On a plain HDMI/analog setup this is normally enough for `"device": null` to just work.

If you want to route through a Bluetooth speaker on modern Raspberry Pi OS (Bookworm and later), audio is managed by **PipeWire** + **WirePlumber**, not the ALSA `default` device directly - `wpctl status` will show the speaker under "Sinks" once paired and connected, even though it won't yet appear in `aplay -L`. `aplay` (a plain ALSA client) can only reach it once the ALSA→PipeWire bridge is installed:
```bash
sudo apt install pipewire-alsa
```
After that, `aplay -L` should show a `pipewire` entry, which either becomes the new ALSA default automatically or can be set explicitly via `"device": "pipewire"`.

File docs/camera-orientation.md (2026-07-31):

# Camera Orientation

If the live viewfinder (or captured photos) comes out flipped or upside down - typically because the HQ camera sensor ended up mounted rotated in the enclosure - correct it with `"hflip"`/`"vflip"` under `"camera"` in [settings.json](../settings.json.example), rather than physically remounting the sensor or rotating images in software after the fact:

```json
"camera": {
    "hflip": true,
    "vflip": true
}
```

Both `true` (the default in this repo's `settings.json`) corrects a sensor mounted rotated 180 degrees; use just one of the two if your image is mirrored on a single axis instead. This is applied once, in the camera's own capture pipeline via `libcamera`'s `Transform`, so it covers the viewfinder, saved photos, and whatever gets sent off for AI editing - not something each part of the app has to individually work around.

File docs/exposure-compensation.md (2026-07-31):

# Exposure Compensation

Small "EV-"/"EV+" buttons in the top corners of the live viewfinder let you bias the exposure by a number of EV stops - enough to rescue a backlit subject (positive EV) or an overexposed bright scene (negative EV). At EV 0 the camera runs fully auto-exposed as normal. Moving off EV 0 snapshots the auto-exposure algorithm's current shutter speed/gain as a baseline, disables auto-exposure, and explicitly sets a shutter speed scaled by `2^EV` from that baseline - every further +/- press rescales from the same baseline rather than the live (now manually-overridden) reading, so repeated presses give a clean, repeatable offset instead of drifting. Auto-exposure resumes as soon as you return to EV 0.

(An earlier version tried to do this via libcamera's `ExposureValue` control, which is meant to bias AE without disabling it - it turned out to be a no-op on this camera/tuning stack, silently accepted but with no effect on the actual shutter speed, hence the explicit snapshot-and-scale approach instead.)

The current EV offset, plus the actual metered shutter speed and gain, are shown at the top of the viewfinder at all times - useful for confirming the buttons are having a real effect, not just changing the on-screen number. The EV offset resets to the default each time the app starts (it isn't saved back to `settings.json`).

Range and step are configurable under `"exposure"` in [settings.json](../settings.json.example):

```json
"exposure": {
    "default": 0.0,
    "step": 0.5,
    "min": -2.0,
    "max": 2.0
}
```

This is separate from the manual aperture ring on the lens itself - that's a physical adjustment outside the app's control, and exposure compensation on top of it works the same way it would on any camera with an auto-exposure mode.

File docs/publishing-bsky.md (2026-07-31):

# Publishing to Bluesky

The **Publish** button (see [Home Screen: Camera Mode vs FTP Mode](home-screen-modes.md)) opens a menu of every configured destination — tapping **Bluesky** there posts the currently displayed photo, using the [atproto](https://atproto.blue) package. This is a sibling of [flickr_publisher.py](../lib/publishers/flickr_publisher.py) in the same pluggable [lib/publishers/](../lib/publishers/) layer — see [Publishing to Flickr](publishing-flickr.md) for the general shape.

## One-time setup

Unlike Flickr, Bluesky doesn't need a browser-based OAuth flow at all — just a handle and an **app password**:

1. Go to [bsky.app/settings/app-passwords](https://bsky.app/settings/app-passwords) while logged into your Bluesky account and create a new app password. Use this, never your real account password — this app stores it in an environment variable, and an app password can be revoked independently if it's ever compromised.
2. Set your handle and the app password as environment variables (same reasoning as the other API keys — never stored in `settings.json`, which is checked into git):
   ```bash
   export BSKY_HANDLE="your-handle.bsky.social"
   export BSKY_APP_PASSWORD="your-bsky-app-password"
   ```

For these to be set automatically every time the app runs (including from the desktop icon), see [Storing API Keys on the Device](api-keys.md) — same as the other keys.

## Configuration

```json
"publish": {
    "bsky": {
        "enabled": true,
        "handle_env": "BSKY_HANDLE",
        "app_password_env": "BSKY_APP_PASSWORD",
        "text": "",
        "alt_text": ""
    }
}
```

* `"enabled"` — set to `false` to take Bluesky out of the Publish menu without deleting the rest of its config; defaults to `true` if omitted.
* `"text"` — fixed text posted with every photo (e.g. a hashtag). Left empty by default.
* `"alt_text"` — accessibility alt text attached to the image itself.

Publishing runs on a background thread, the same way the AI edit does, so the app stays responsive during the upload. Note that Bluesky rejects images over roughly 1MB — this app doesn't currently downscale before upload, so very large photos may fail to publish with an error from the server.

If a camera-mode device and an FTP-mode device both publish to the same Bluesky account, each needs its own `BSKY_HANDLE`/`BSKY_APP_PASSWORD` environment variables set (they can be the same account's credentials, or you can create a separate app password per device so either can be revoked independently).

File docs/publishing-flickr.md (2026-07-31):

# Publishing to Flickr

The **Publish** button (see [Home Screen: Camera Mode vs FTP Mode](home-screen-modes.md)) opens a menu of every configured destination — tapping **Flickr** there uploads the currently displayed photo, tagged with whatever's configured in `settings.json`. This is built as a pluggable layer in [lib/publishers/](../lib/publishers/) — the same shape as [lib/displays/](../lib/displays/). [Bluesky](publishing-bsky.md) is already a sibling of `flickr_publisher.py`, alongside the self-hosted Custard Cream Server backend; other services (Instagram, whatever) could be added the same way, without touching `custard_cream_camera.py` beyond a new branch in `publishers/create_publisher()` and an entry in `PUBLISHER_LABELS`.

## One-time setup

Flickr uses OAuth 1.0a, which needs a real browser to authorize the app — but only **once per device**. This is deliberately kept separate from the main app:

1. Get an API key and secret from [flickr.com/services/apps/create](https://www.flickr.com/services/apps/create/) (needs your Pro account login).
2. Set them as environment variables (same reasoning as the Gemini API key — never stored in `settings.json`, which is checked into git):
   ```bash
   export FLICKR_API_KEY="your-api-key"
   export FLICKR_API_SECRET="your-api-secret"
   ```
3. Run the one-time setup script:
   ```bash
   python setup_flickr_auth.py
   ```
   It prints a URL — open it in a browser on *any* device (your phone is fine, it doesn't have to be the Pi), log into Flickr, authorize the app, and paste the verification code it gives you back into the terminal. This caches an access token locally (via `flickrapi`'s own cache, typically `~/.flickr/`).

   If this app has already been authorized on a *different* device (e.g. one running in the other mode), this still needs running again here — the cached token lives per-machine, not in this repo, so each device that publishes to Flickr needs its own one-time authorization.

   Prefer a device other than the one running the app for opening the browser if you can: doing it directly on that device's own desktop can trigger a keyring/password dialog that stays open (and stays modal) behind the app afterwards, silently blocking all clicks until it's dismissed — see [Touch/clicks stop responding](display-backends.md#touchclicks-stop-responding-but-the-cursor-still-moves).

After that, **Publish** works with no further browser interaction — `custard_cream_camera.py` only ever does the upload itself, using the cached token. If it's ever missing or expired, publishing fails with a clear message pointing back at this script rather than trying to prompt interactively (there's no browser available from a background upload thread).

For these to be set automatically every time the app runs (including from the desktop icon), see [Storing API Keys on the Device](api-keys.md) — same as the Gemini API key.

## Configuration

```json
"publish": {
    "flickr": {
        "enabled": true,
        "api_key_env": "FLICKR_API_KEY",
        "api_secret_env": "FLICKR_API_SECRET",
        "tags": "custardcreamcamera",
        "is_public": true,
        "token_cache_dir": null
    }
}
```

* `"enabled"` — set to `false` to take Flickr out of the Publish menu without deleting the rest of its config; defaults to `true` if omitted.
* `"tags"` — space-separated tags applied to every upload; multi-word tags need their own quotes inside the string, e.g. `"tags": "custardcreamcamera \"family holiday\""`.
* `"is_public"` — `true` posts immediately visible to anyone on Flickr; set `false` for private (only you) instead.
* `"token_cache_dir"` — leave `null` to use `flickrapi`'s own default cache location; only set this if you need the token stored somewhere specific.

Every enabled destination under `"publish"` shows up as its own button in the Publish menu. If only one destination ends up enabled, Publish skips the menu entirely and sends straight to it.

Publishing runs on a background thread, the same way the AI edit does, so the app stays responsive during the upload.

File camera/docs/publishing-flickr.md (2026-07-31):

# Publishing to Flickr

The **Publish** button (in [Play mode](capture-and-play-modes.md)) opens a menu of every configured destination — tapping **Flickr** there uploads the currently displayed photo, tagged with whatever's configured in `settings.json`. This is built as a pluggable layer in [lib/publishers/](../../lib/publishers/) — the same shape as [lib/displays/](../../lib/displays/) — and shared unchanged with the [host app](../../host/). [Bluesky](publishing-bsky.md) is already a sibling of `flickr_publisher.py`, alongside the self-hosted Custard Cream Server backend; other services (Instagram, whatever) could be added the same way, without touching `custard_cream_camera.py` beyond a new branch in `publishers/create_publisher()` and an entry in `PUBLISHER_LABELS`.

## One-time setup

Flickr uses OAuth 1.0a, which needs a real browser to authorize the app — but only **once**. This is deliberately kept separate from the main camera app:

1. Get an API key and secret from [flickr.com/services/apps/create](https://www.flickr.com/services/apps/create/) (needs your Pro account login).
2. Set them as environment variables (same reasoning as the Gemini API key — never stored in `settings.json`, which is checked into git):
   ```bash
   export FLICKR_API_KEY="your-api-key"
   export FLICKR_API_SECRET="your-api-secret"
   ```
3. Run the one-time setup script:
   ```bash
   python setup_flickr_auth.py
   ```
   It prints a URL — open it in a browser on *any* device (your phone is fine, it doesn't have to be the Pi), log into Flickr, authorize the app, and paste the verification code it gives you back into the terminal. This caches an access token locally (via `flickrapi`'s own cache, typically `~/.flickr/`).

   Prefer a device other than the Pi for this if you can: opening the browser directly on the Pi's own desktop can trigger a keyring/password dialog that stays open (and stays modal) behind the camera app afterwards, silently blocking all clicks until it's dismissed — see [Touch/clicks stop responding](display-backends.md#touchclicks-stop-responding-but-the-cursor-still-moves) in the display backends doc.

After that, **Publish** works with no further browser interaction — `custard_cream_camera.py` only ever does the upload itself, using the cached token. If it's ever missing or expired, publishing fails with a clear message pointing back at this script rather than trying to prompt interactively (there's no browser available from a background upload thread).

For these to be set automatically every time the app runs (including from the desktop icon), see [Storing API Keys on the Device](api-keys.md) — same as the Gemini API key.

## Configuration

```json
"publish": {
    "flickr": {
        "enabled": true,
        "api_key_env": "FLICKR_API_KEY",
        "api_secret_env": "FLICKR_API_SECRET",
        "tags": "custardcreamcamera",
        "is_public": true,
        "token_cache_dir": null
    }
}
```

* `"enabled"` — set to `false` to take Flickr out of the Publish menu without deleting the rest of its config; defaults to `true` if omitted.
* `"tags"` — space-separated tags applied to every upload; multi-word tags need their own quotes inside the string, e.g. `"tags": "custardcreamcamera \"family holiday\""`.
* `"is_public"` — `true` posts immediately visible to anyone on Flickr; set `false` for private (only you) instead.
* `"token_cache_dir"` — leave `null` to use `flickrapi`'s own default cache location; only set this if you need the token stored somewhere specific.

Every enabled destination under `"publish"` shows up as its own button in the Publish menu. If only one destination ends up enabled, Publish skips the menu entirely and sends straight to it.

Publishing runs on a background thread, the same way the AI edit does, so the viewfinder and other buttons stay responsive during the upload.

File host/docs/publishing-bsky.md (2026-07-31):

# Publishing to Bluesky

The **Publish** button (see [Reviewing Received Photos](reviewing-photos.md)) opens a menu of every configured destination — tapping **Bluesky** there posts the currently displayed photo, using the [atproto](https://atproto.blue) package. This is a sibling of [flickr_publisher.py](../../lib/publishers/flickr_publisher.py) in the same pluggable [lib/publishers/](../../lib/publishers/) layer (shared unchanged with the [camera app](../../camera/)) — see [Publishing to Flickr](publishing-flickr.md) for the general shape.

## One-time setup

Unlike Flickr, Bluesky doesn't need a browser-based OAuth flow at all — just a handle and an **app password**:

1. Go to [bsky.app/settings/app-passwords](https://bsky.app/settings/app-passwords) while logged into your Bluesky account and create a new app password. Use this, never your real account password — this app stores it in an environment variable, and an app password can be revoked independently if it's ever compromised.
2. Set your handle and the app password as environment variables (same reasoning as the other API keys — never stored in `settings.json`, which is checked into git):
   ```bash
   export BSKY_HANDLE="your-handle.bsky.social"
   export BSKY_APP_PASSWORD="your-bsky-app-password"
   ```

For these to be set automatically every time the app runs (including from the desktop icon), see [Storing API Keys on the Device](api-keys.md) — same as the other keys.

## Configuration

```json
"publish": {
    "bsky": {
        "enabled": true,
        "handle_env": "BSKY_HANDLE",
        "app_password_env": "BSKY_APP_PASSWORD",
        "text": "",
        "alt_text": ""
    }
}
```

* `"enabled"` — set to `false` to take Bluesky out of the Publish menu without deleting the rest of its config; defaults to `true` if omitted.
* `"text"` — fixed text posted with every photo (e.g. a hashtag). Left empty by default.
* `"alt_text"` — accessibility alt text attached to the image itself.

Publishing runs on a background thread, so the app stays responsive during the upload. Note that Bluesky rejects images over roughly 1MB — neither this app nor the camera app currently downscale before upload, so very large photos may fail to publish with an error from the server.

If both this app and the camera app publish to the same Bluesky account, each needs its own `BSKY_HANDLE`/`BSKY_APP_PASSWORD` environment variables set (they can be the same account's credentials, or you can create a separate app password per device so either can be revoked independently).

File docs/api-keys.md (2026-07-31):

# Storing API Keys on the Device

API keys are needed depending on which features you use:

* `GOOGLE_API_KEY` — [Voice-Prompted AI Edits](voice-ai-edits.md), from [aistudio.google.com/apikey](https://aistudio.google.com/apikey).
* `FLICKR_API_KEY` / `FLICKR_API_SECRET` — [Publishing to Flickr](publishing-flickr.md), from [flickr.com/services/apps/create](https://www.flickr.com/services/apps/create/).
* `BSKY_HANDLE` / `BSKY_APP_PASSWORD` — [Publishing to Bluesky](publishing-bsky.md), an app password from [bsky.app/settings/app-passwords](https://bsky.app/settings/app-passwords) (not your main account password).
* `CUSTARD_CREAM_SERVER_EMAIL` / `CUSTARD_CREAM_SERVER_PASSWORD` — publishing to a self-hosted custard-cream-server instance, the login for this device's account on that server.

All of these are read from environment variables, never from `settings.json` — that file is checked into git, so committing real keys into it would leak them into the repo's history. The question this page actually answers is: how do you make sure those environment variables are set automatically every time the app starts on the device, without typing `export` by hand each session?

If you run this app on more than one device (e.g. one in camera mode, one in FTP mode), each device reads its own `secrets.sh` and has its own environment — even if both publish to the same accounts, the keys aren't shared between devices just because the repo is.

There are two practical ways to do it. **Use the first one** unless you have a specific reason not to.

## Option A: `secrets.sh`, sourced by the launcher (recommended)

[run_custard_cream_camera.sh](../run_custard_cream_camera.sh) automatically sources `secrets.sh` next to it, if that file exists, before starting the app - this works regardless of how the app is launched (terminal, desktop icon, application menu), since it's the launcher script itself doing the sourcing rather than relying on some shell startup mechanism to have run first.

`secrets.sh` is listed in `.gitignore`, so it's never committed - only [secrets.sh.example](../secrets.sh.example) (a template with placeholder values) is tracked in git.

To set it up:

```bash
cp secrets.sh.example secrets.sh
chmod 600 secrets.sh   # readable/writable by you only
```

Then edit `secrets.sh` and fill in real values:

```bash
export GOOGLE_API_KEY="your-gemini-api-key"
export FLICKR_API_KEY="your-flickr-api-key"
export FLICKR_API_SECRET="your-flickr-api-secret"
export BSKY_HANDLE="your-handle.bsky.social"
export BSKY_APP_PASSWORD="your-bsky-app-password"
```

That's it - `run_custard_cream_camera.sh` picks it up automatically next time it runs, whether that's from a terminal or the desktop icon.

**Why not just paste the `export` lines directly into `run_custard_cream_camera.sh` itself?** That file *is* tracked in git - editing it directly with real keys risks accidentally committing them (e.g. a routine `git add -A` before a commit). Keeping the keys in a separate gitignored file sidesteps that risk entirely, at the cost of one extra file to create.

## Option B: shell configuration (`~/.bashrc`)

Add the `export` lines to `~/.bashrc` (or `~/.profile`, depending on your shell setup):

```bash
export GOOGLE_API_KEY="your-gemini-api-key"
export FLICKR_API_KEY="your-flickr-api-key"
export FLICKR_API_SECRET="your-flickr-api-secret"
export BSKY_HANDLE="your-handle.bsky.social"
export BSKY_APP_PASSWORD="your-bsky-app-password"
```

This works reliably when you launch the app **from a terminal**, since interactive shells source `~/.bashrc` automatically.

It's less reliable from the **desktop icon**: `.desktop` files typically exec the launcher script directly rather than through a login/interactive shell, so `~/.bashrc` doesn't always get sourced first - behavior varies by desktop environment. If you go this route and a desktop-icon launch can't see the keys, `custard_cream_camera.log` (or the terminal, if `Terminal=true` in [custard-cream-camera.desktop](../custard-cream-camera.desktop)) will show a clear error like `No API key found in environment variable 'GOOGLE_API_KEY'...` rather than failing silently - see [Running the App](running-the-app.md).

## Which to use

* Only ever launching from a terminal? Either works equally well.
* Launching from the desktop icon (the common case for a device with no keyboard)? Use **Option A** - it's the one guaranteed to work regardless of desktop environment quirks, since it doesn't depend on anything outside the app's own launcher script.

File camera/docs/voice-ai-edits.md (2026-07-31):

# Voice-Prompted AI Edits

In [Play mode](capture-and-play-modes.md), hold **Speak** (or use the shutter remote's speak key, which works from any mode), say an editing instruction (e.g. "make it look like a watercolor painting"), and release. The app transcribes what you said, then shows you the transcript with three options before anything is sent anywhere for editing:

* **Send** — sends it, with the currently displayed image, to Google's Gemini ("Nano Banana") image model for editing.
* **Reject** — discards it. Nothing is sent for editing; you're back where you started.
* **Edit** — opens an on-screen keyboard to correct the text (misheard words, added detail, etc.), then returns to this same Send/Reject/Edit screen with the corrected text.

This review step exists because speech recognition isn't perfect, and a misheard instruction sent straight to an image-editing model wastes a request (and, depending on your Gemini plan, a quota unit) on a result you never wanted. Once sent, the result is saved to `captures/` as `ai_<timestamp>.jpg`, shown on screen for a few seconds, and becomes the new current selection in Play mode. Image editing always goes through Gemini; the viewfinder and other buttons stay responsive while it's working since the network calls run on a background thread.

Transcription (turning your speech into the text prompt) is a **pluggable backend**, selected via `"transcribe_provider"` under `"custard_cream"` in [settings.json](../settings.json):

- **`"vosk"` (the shipped default)** — runs entirely on the Pi via a local [Vosk](https://alphacephei.com/vosk/) model, no network round-trip. Since it recognises speech live, the transcript is displayed on screen as you talk, updating word by word while **Speak** is still held. Implemented in [lib/transcription/vosk_transcriber.py](../../lib/transcription/vosk_transcriber.py).
- **`"gemini"`** — sends the whole recording to Gemini once you release **Speak**, same as this feature originally worked. No live text — just the "Recording... release to send" banner until it's done. Implemented in [lib/transcription/gemini_transcriber.py](../../lib/transcription/gemini_transcriber.py).

Both backends implement the same interface ([lib/transcription/base.py](../../lib/transcription/base.py)), selected by [lib/transcription/__init__.py](../../lib/transcription/__init__.py)'s `create_transcriber()` — the same plugin pattern used for [publishers](../../lib/publishers/) and [displays](../../lib/displays/). Image editing itself is unaffected by this choice and stays in [lib/NanoBananaClient.py](../../lib/NanoBananaClient.py). The whole flow (`start_voice_prompt()`/`finish_voice_prompt()`/`review_ai_prompt()`/`run_ai_edit()`/...) lives in [lib/review_station.py](../../lib/review_station.py), shared with the [host app](../../host/).

## Setup

1. **Get a Gemini API key.** Go to [aistudio.google.com/apikey](https://aistudio.google.com/apikey), sign in with a Google account, and create a key. This is needed for image editing regardless of transcription backend, and for transcription itself if you use `"gemini"`.

2. **Make sure the SDKs are installed.** `google-genai` and `vosk` are both already in [requirements.txt](../requirements.txt), pulled in by the normal `pip install -r requirements.txt` venv setup — nothing extra needed unless your venv predates those being added.

3. **Set the API key as an environment variable.** `NanoBananaClient.py` reads it from `GOOGLE_API_KEY` by default (the variable name is itself configurable via `"api_key_env"` under `"custard_cream"` in settings.json) — deliberately *not* stored in `settings.json`, since that file is checked into git. For a quick one-off test from a terminal:
   ```bash
   export GOOGLE_API_KEY="your-api-key"
   ```
   For it to be set automatically every time the app runs (including from the desktop icon, with no terminal involved) see [Storing API Keys on the Device](api-keys.md).

4. **If using Vosk, download a model.** See [Installing Vosk](venv-setup.md#installing-vosk-local-speech-recognition) for the exact download/unzip commands and a one-liner to verify it loads. The default settings expect `vosk-model-small-en-us-0.15` (~40MB) unzipped to `models/vosk-model-small-en-us-0.15`, matching `"custard_cream.vosk.model_path"` in settings.json — adjust that setting if you use a different model or location. **This is loaded once at app startup** (not on first Speak press, to avoid a delay on first use) — a missing or wrong `model_path` will fail app startup entirely, not just the Speak feature, so get this right before relying on Vosk as the active provider.

5. **Check the microphone.** Both backends need `arecord` (part of `alsa-utils`, normally already installed on Raspberry Pi OS — `sudo apt install alsa-utils` if not). Confirm it works standalone first:
   ```bash
   arecord -f S16_LE -r 16000 -c 1 -d 3 test.wav && aplay test.wav
   ```
   If you have multiple audio devices, set `"device"` under `"custard_cream"` in settings.json to the right ALSA device name (`arecord -l` lists them) — it's `null` by default, which uses the system default input. This is shared by both transcription backends, since it's a property of the physical mic, not the transcriber.

6. **Test it.** [Play mode](capture-and-play-modes.md) has no option to take a fresh photo, so press **Click** first (in Capture mode) if you haven't taken any yet. Then: launch the app, tap **Play**, hold **Speak**, say something like "make it look like a watercolor painting" (if using Vosk, watch the recognised text build up on screen as you talk), and release. The edited image should then appear on screen and save to `captures/ai_<timestamp>.jpg`.

Recording length and the result's on-screen hold time are also configurable under `"custard_cream"` in settings.json. The Gemini model IDs (`transcribe_model`, `edit_model`) may need adjusting as Google's model naming evolves — check the current names in the [Gemini API docs](https://ai.google.dev/gemini-api/docs/models) if editing (or Gemini-backend transcription) fails with a "model not found" style error.

## Diagnostics

Progress is shown on screen as well as logged. While a request is in flight, the banner that would otherwise just say "Processing..." instead shows what's actually happening: "Transcribing...", then (once you've reviewed and sent the prompt) "Sending image for processing...", then "Received result, saving..." — the same on-screen-diagnostics idea used for [printing](printing.md), applied to this workflow.

Every stage also prints a `Speak: ...` line to the terminal (or `custard_cream_camera.log`), so a stuck or failed edit can be narrowed down to exactly where it stopped: recording start/stop, transcription (whichever backend is active) and its result, whether the prompt was sent/rejected at the review step, the request sent for image editing, and the response received (including any text the model returned instead of an image, e.g. a safety refusal — normally invisible on screen, since the caller only ever sees `None`).

Requests to Gemini time out after `"timeout_seconds"` (default `30`) under `"custard_cream"` in settings.json — without this, a stalled connection (flaky wifi, a network path that silently drops packets) would hang indefinitely with no error and no diagnostic output at all. This only applies to work that actually goes over the network: image editing always, and transcription only when `"transcribe_provider"` is `"gemini"` — Vosk transcription is local and isn't affected by connectivity at all. If a Gemini-backed request hangs repeatedly even with a normally-reliable connection, try raising `"timeout_seconds"` in case it's just Gemini being slow rather than the connection actually stalling.

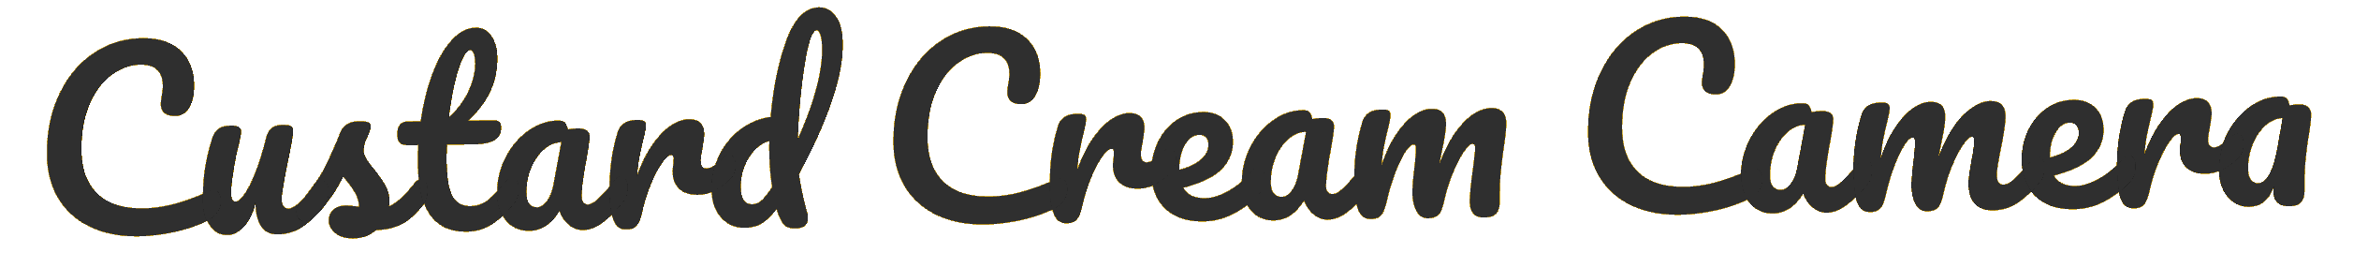
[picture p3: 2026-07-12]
assets/images/watermark.png

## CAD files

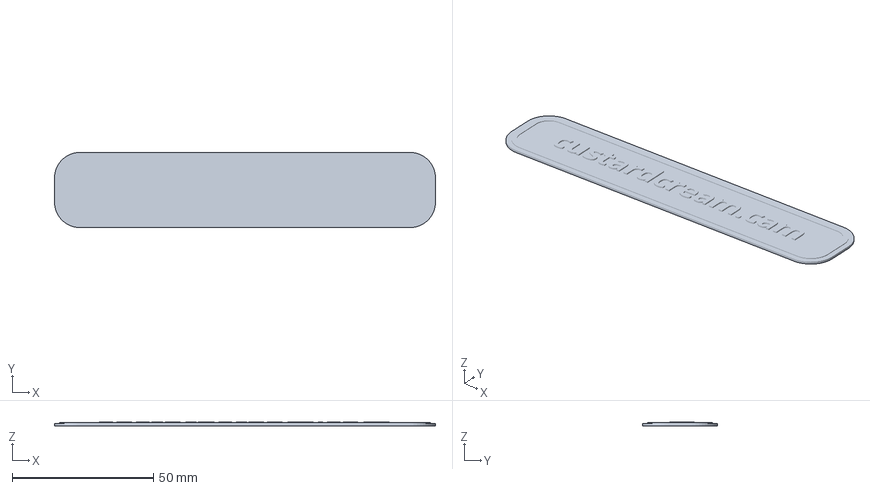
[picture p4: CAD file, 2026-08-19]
case/custardcream web address.3mf
135.0 x 26.6 x 1.44 mm

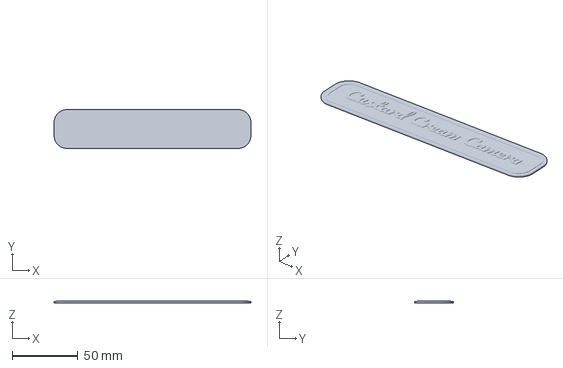
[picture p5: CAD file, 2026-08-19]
case/sign.3mf
150.0 x 29.6 x 1.60 mm

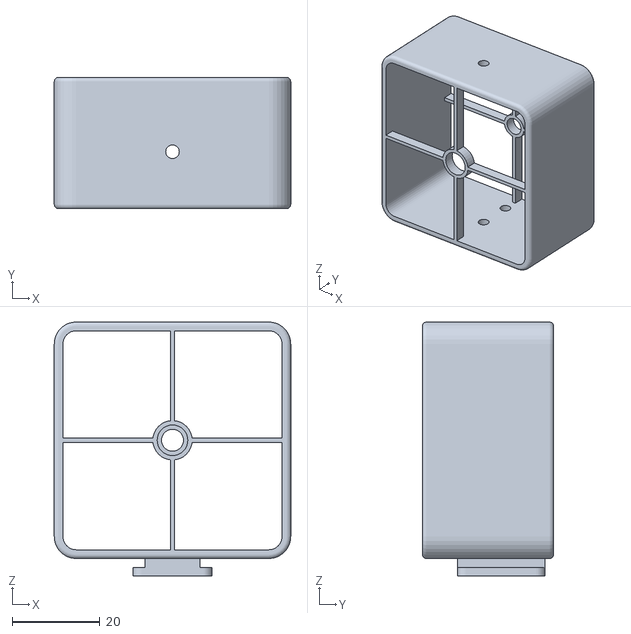
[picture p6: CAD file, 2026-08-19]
case/viewfinder.stl
54.0 x 30.0 x 58.0

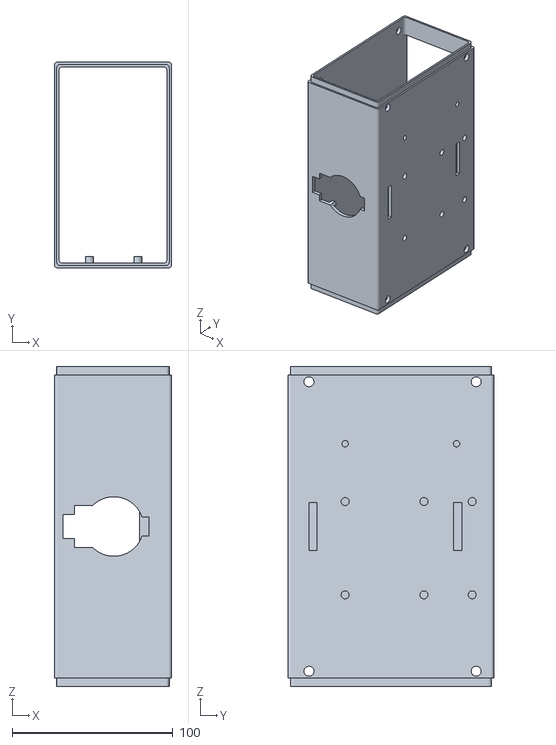
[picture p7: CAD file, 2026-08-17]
case/BatteryBase.stl
73.0 x 128.0 x 199.0

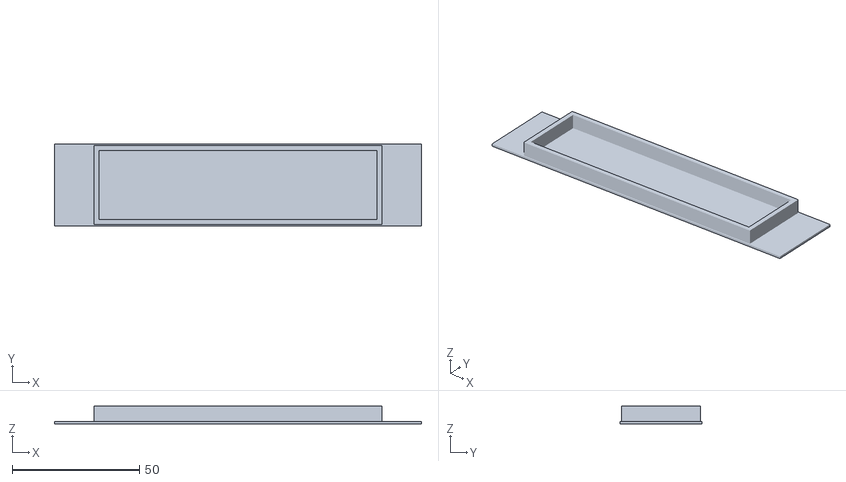
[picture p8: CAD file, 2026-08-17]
case/paperLid.stl
144.0 x 32.0 x 7.00

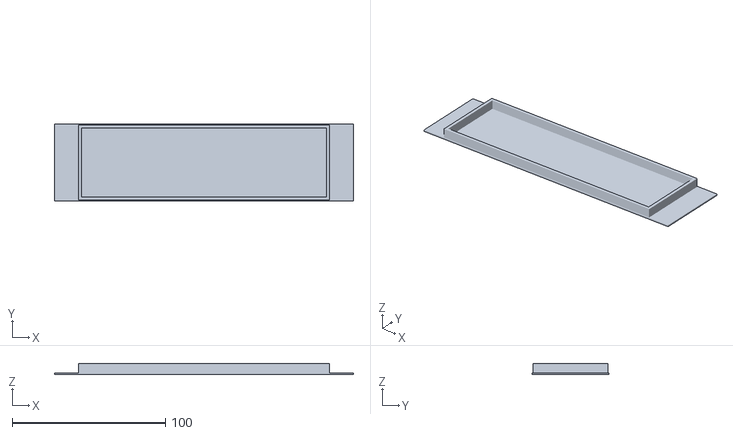
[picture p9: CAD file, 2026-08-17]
case/batteryHolderLid.stl
195.0 x 50.0 x 7.00

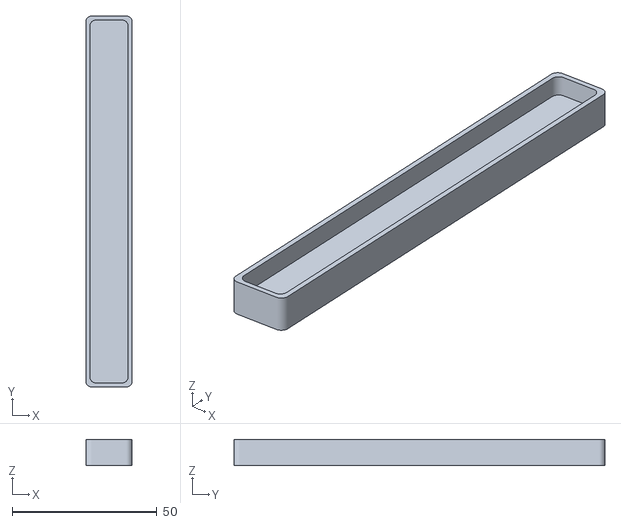
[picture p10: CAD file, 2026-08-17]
case/HandleBaseLid.stl
16.0 x 128.0 x 9.00

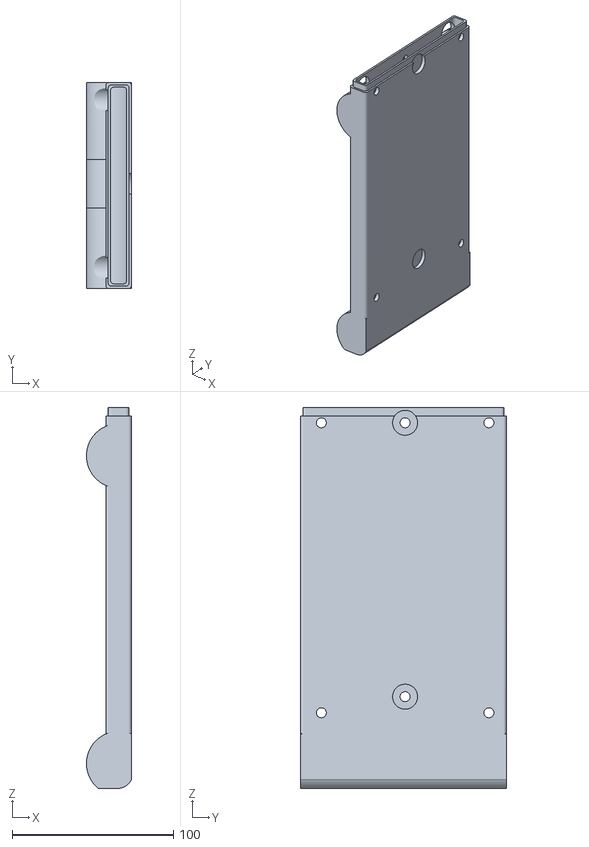
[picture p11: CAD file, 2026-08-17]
case/HandleBase.stl
28.0 x 128.0 x 236.5

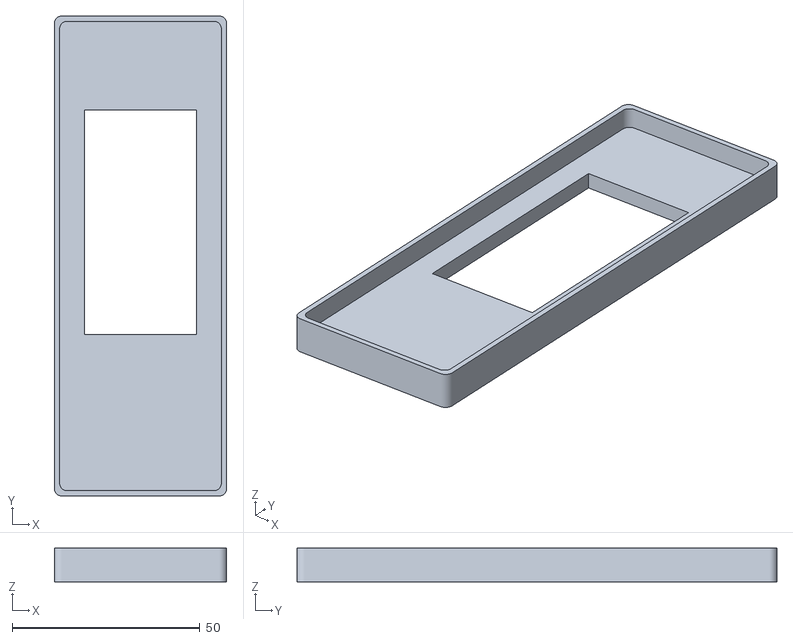
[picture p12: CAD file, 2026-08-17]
case/ControllerLeftLid.stl
46.0 x 128.0 x 9.00

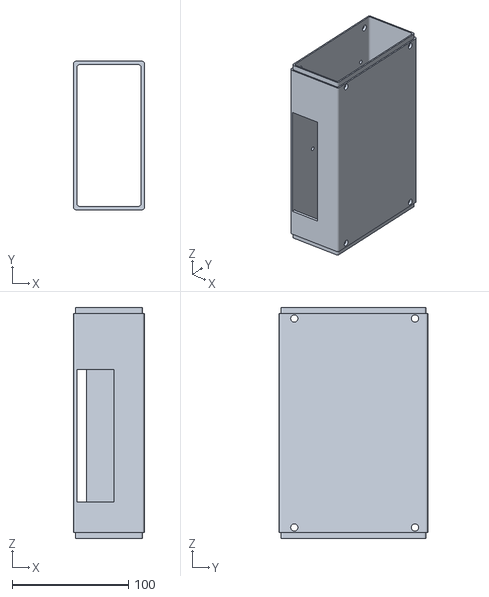
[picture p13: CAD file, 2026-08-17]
case/PrinterBase.stl
61.0 x 128.0 x 199.0

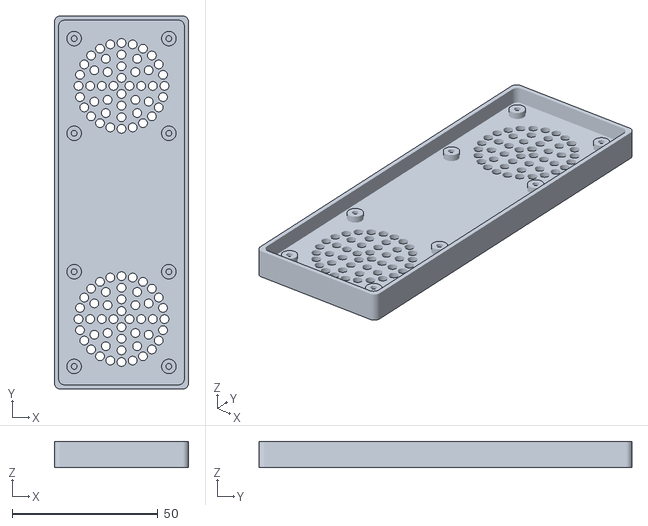
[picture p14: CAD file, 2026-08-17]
case/ControllerSpeakerLid.stl
46.0 x 128.0 x 9.00

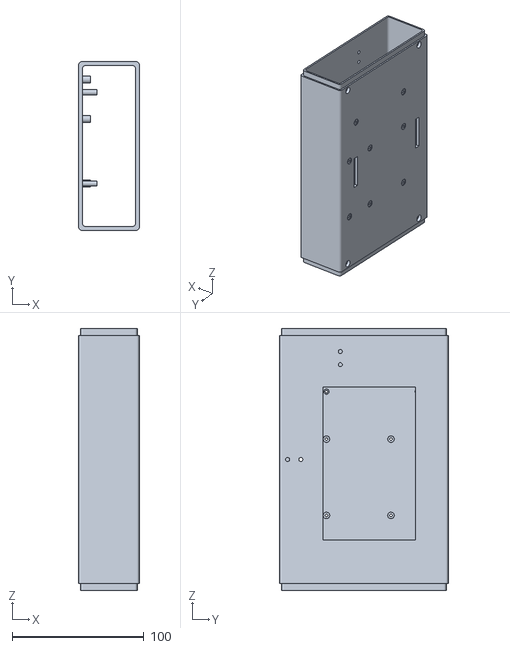
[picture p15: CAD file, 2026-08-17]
case/ControllerBase.stl
46.0 x 128.0 x 199.0

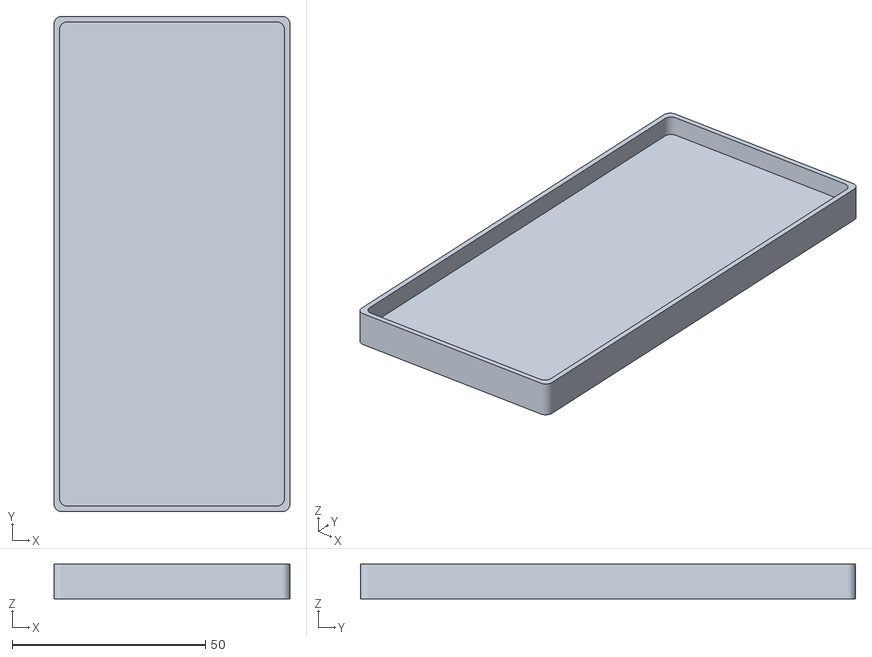
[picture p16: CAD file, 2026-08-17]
case/PrinterLidLeft.stl
61.0 x 128.0 x 9.00

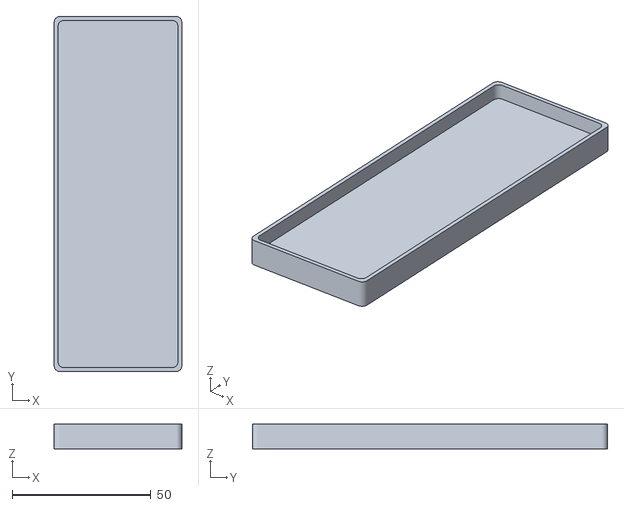
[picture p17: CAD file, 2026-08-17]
case/ControllerLid.stl
46.0 x 128.0 x 9.00

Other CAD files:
case/BatteryLidLeft.stl
case/BatteryLidRight.stl
case/PrinterLidRight.stl

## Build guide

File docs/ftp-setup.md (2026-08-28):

# Receiving Photos over FTP

The Sony A7R IV can upload JPEGs (optionally alongside RAW) to an FTP server automatically after each shot, or on demand for selected images, via its built-in FTP-transfer feature. This app runs that FTP server - [lib/ftp_server.py](../lib/ftp_server.py), built on [pyftpdlib](https://pyftpdlib.readthedocs.io/) - whenever `settings.json`'s `"mode"` is `"ftp"` or `"camera_ftp"`, and shows each upload as it arrives, using the same review/print/publish/voice-edit flow as camera mode's Play mode (see [Home Screen: Camera Mode vs FTP Mode](home-screen-modes.md)).

## Configuring the app

The `"ftp"` block in [settings.json](../settings.json.example):

```json
"ftp": {
    "host": "0.0.0.0",
    "port": 2121,
    "username": "sony",
    "password": "changeme",
    "incoming_dir": "ftp_incoming"
}
```

* `"host"` — the address to listen on. `0.0.0.0` (the default) listens on every network interface this device has; narrow it to a specific address if you want the server reachable only over one of them (e.g. a dedicated Wi-Fi network shared with the camera).
* `"port"` — deliberately **not** the standard FTP port 21: binding a port below 1024 needs root (or a `setcap` grant) on Linux, which this app doesn't ask for. Use whatever custom port you set here as the camera's FTP server port too - both sides just need to agree.
* `"username"`/`"password"` — change these from the shipped defaults. This is a plain-auth FTP server with no TLS by default; treat it as trusted-LAN-only (see [Security notes](#security-notes) below), not something to expose to the open internet.
* `"incoming_dir"` — a scratch folder (relative to this app's own directory, gitignored) the camera's FTP session actually writes into. You never need to look in here directly - see [How uploads get flattened](#how-uploads-get-flattened-into-captures).

## Configuring the camera

Exact menu wording varies by firmware version, so treat this as a guide rather than an exact click-by-click script - consult Sony's current manual for your firmware if a step doesn't match what you see:

1. On the camera, go to the network/FTP transfer settings (under the Network menu on recent firmware) and set up an FTP connection: server address/hostname = this device's IP address on your shared network, port = whatever you set `"ftp"."port"` to above (not 21), username/password = whatever you set above.
2. Set the connection method to **Wired LAN**, **Wi-Fi**, or via a smartphone/USB tether, depending on how this device and the camera are actually networked - they need to be able to reach each other, e.g. both on the same Wi-Fi network, or connected directly via the camera's Wi-Fi access-point mode.
3. Set **FTP Transfer** (or **Auto Transfer during REC** / equivalent for your firmware) to on, and choose whether it uploads every shot automatically or only images you mark for transfer during playback - either works fine with this app, since it just reacts to whatever arrives.
4. Leave the camera's own "target folder" / date-folder option at whatever default it offers - it doesn't matter which folder structure the camera creates on the server, see below.

## How uploads get flattened into `captures/`

Sony's FTP client may create a dated subfolder (e.g. `2026_07_28`) under the server root and upload into that, depending on camera settings and firmware - this app doesn't rely on any particular behavior here. `ftp_server.py`'s `on_file_received()` callback fires once a file finishes uploading, wherever under `incoming_dir` it landed, and:

1. Ignores it (leaving it in place, untouched) if it's not a `.jpg`/`.jpeg` file - e.g. a RAW `.ARW` file from simultaneous RAW+JPEG capture is stored but never previewed.
2. Otherwise moves it into `captures/` (flat, no subfolders) with a lower-cased `.jpg` extension - cameras write e.g. `DSC01234.JPG`, and the shared review code globs `*.jpg`, which is case-sensitive on Linux; without lower-casing, uploaded photos would silently never appear.
3. Renames on collision (`_2`, `_3`, ...) rather than overwriting, in the rare case two uploads produce the same filename (e.g. after the camera's internal file counter wraps around).

The photo then becomes the current selection on screen immediately - see [When a new photo arrives](home-screen-modes.md#when-a-new-photo-arrives).

## Testing without a camera

Any FTP client can stand in for the camera while testing:

```bash
curl -T some_photo.jpg "ftp://sony:changeme@<this-device-ip>:2121/"
```

If that shows up on screen, the camera side is just a matter of getting its FTP settings to match.

## Security notes

This FTP server accepts plain-text username/password auth with no encryption, and grants the configured user just enough permission to list, create a subfolder, and write files (`elmw` - see `ftp_server.py`) - no read-back or delete. That's appropriate for a device on a private/trusted network talking only to your own camera, but:

* Don't forward this port through your router to the public internet.
* Change the default `"username"`/`"password"` in `settings.json` before relying on this.
* If the camera and this device share Wi-Fi with other devices you don't fully trust, consider the camera's own Wi-Fi access-point mode (a direct camera-to-device connection) instead of a shared network.

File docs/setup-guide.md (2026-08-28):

# Setting Up From Scratch

A step-by-step walkthrough for taking a fresh Raspberry Pi OS install to a running Custard Cream
Camera. Follow the steps in order — later steps assume earlier ones are done. Each step links to a
dedicated doc for full detail/troubleshooting; this page is the map that ties them together and
tells you what order to actually do them in.

If you're setting up more than one physical device (e.g. one camera, one FTP receiver), repeat this
whole guide independently for each one — every device gets its own clone, venv, `secrets.sh`, and
`settings.json`; nothing is shared between them.

## 1. Decide the mode

`settings.json`'s `"mode"` key picks the home screen this device shows, and affects several of the
steps below:

* **`"camera"`** — a live viewfinder with Capture/Play modes; this device has a Pi camera attached.
* **`"ftp"`** — no camera; this device receives JPEGs over FTP from a real camera (e.g. a Sony
  body's FTP-transfer feature) and is always in Play mode.
* **`"camera_ftp"`** — both: a Pi camera *and* the FTP receiver running at the same time. Follow
  every step below tagged either **[camera mode]** or **[FTP mode]** — skip nothing.

See [Home Screen: Camera Mode vs FTP Mode](home-screen-modes.md) for exactly what differs. Steps
below are marked **[camera mode]** or **[FTP mode]** where they only apply to one.

## 2. Get the code onto the device

```bash
git clone https://github.com/CrazyRobMiles/custard-cream-camera.git
cd custard-cream-camera
```

## 3. Install system packages

These come from `apt`, not `pip` — see [Setting Up the Python Virtual Environment](venv-setup.md)
for why `picamera2` in particular has to be installed this way. (`"camera_ftp"` devices: follow
**[camera mode]** here and in steps 4-5 below — it's a strict superset of what **[FTP mode]** needs,
since the FTP receiver's own dependency, `pyftpdlib`, is a `pip` package already in the common
`requirements.txt`, not an `apt` one.)

**[camera mode]**
```bash
sudo apt update
sudo apt install -y python3-picamera2 python3-libcamera python3-venv libcups2-dev python3-tk
```

**[FTP mode]**
```bash
sudo apt update
sudo apt install -y python3-venv libcups2-dev python3-tk
```

(`python3-tk` is only needed if you use the `hdmi-desktop` display backend — the default and, at
the moment, the only one — see [Display Backends](display-backends.md).)

## 4. Create and activate the virtual environment

**[camera mode]** needs `--system-site-packages` so the venv can see the apt-installed
`picamera2`/`libcamera`:
```bash
python3 -m venv --system-site-packages venv
```

**[FTP mode]** a plain, fully-isolated venv is enough:
```bash
python3 -m venv venv
```

Then, either mode:
```bash
source venv/bin/activate
python -m pip install --upgrade pip
```

Full detail (recreating the environment, verifying camera support, etc.) is in
[Setting Up the Python Virtual Environment](venv-setup.md).

## 5. Install Python dependencies

Common packages, either mode:
```bash
python -m pip install -r requirements.txt
```

**[camera mode] only** — `picamera2` itself:
```bash
python -m pip install -r requirements-camera.txt
```

**Only if you'll use voice AI edits with the local Vosk transcriber** (step 10 below covers whether
you need this):
```bash
python -m pip install -r requirements-vosk.txt
```
— then download a Vosk model; see
[Installing Vosk](venv-setup.md#installing-vosk-local-speech-recognition) for the exact commands.

## 6. Create `settings.json`

```bash
cp settings.json.example settings.json
```

Set `"mode"` to `"camera"`, `"ftp"`, or `"camera_ftp"` per step 1. Everything below edits this same file — it's
listed in `.gitignore`, so it's device-local config: a `git pull` on this device never overwrites
it, and none of the values you set below get committed back to the repo.

## 7. Configure the display

Check `"display"` in `settings.json` matches your screen's actual resolution:
```json
"display": { "type": "hdmi-desktop", "width": 800, "height": 480 }
```
See [Display Backends](display-backends.md) for what `width`/`height` mean and how to fix a blank
window (`DISPLAY`/`XDG_RUNTIME_DIR` not set — common over SSH).

## 8. [camera mode] Fix the viewfinder orientation

If the live preview comes out upside-down or mirrored (common — the sensor is often mounted rotated
in the enclosure), set `"hflip"`/`"vflip"` under `"camera"` in `settings.json` before going further,
since every later camera-mode step assumes you're looking at a correctly-oriented preview. See
[Camera Orientation](camera-orientation.md).

## 9. [FTP mode] Configure the FTP receiver

Set the `"ftp"` block in `settings.json` (host/port/username/password), then configure the sending
camera's FTP-transfer feature to point at this device. Full walkthrough, including a way to test it
without a real camera: [Receiving Photos over FTP](ftp-setup.md).

## 10. Decide which optional features you need, and get API keys for them

Everything below this point is optional — skip whichever features you don't need. Each one needs an
API key stored as an environment variable (never in `settings.json`, since that's checked into
git). Set up however many of these you actually plan to use:

| Feature | Env vars needed | Where to get them |
|---|---|---|
| [Voice-Prompted AI Edits](voice-ai-edits.md) | `GOOGLE_API_KEY` | [aistudio.google.com/apikey](https://aistudio.google.com/apikey) |
| [Publishing to Flickr](publishing-flickr.md) | `FLICKR_API_KEY`, `FLICKR_API_SECRET` | [flickr.com/services/apps/create](https://www.flickr.com/services/apps/create/) |
| [Publishing to Bluesky](publishing-bsky.md) | `BSKY_HANDLE`, `BSKY_APP_PASSWORD` | [bsky.app/settings/app-passwords](https://bsky.app/settings/app-passwords) |
| Publishing to a self-hosted Custard Cream Server | `CUSTARD_CREAM_SERVER_EMAIL`, `CUSTARD_CREAM_SERVER_PASSWORD` | your server account's login |

To make these available to the app automatically on every launch (including from a desktop icon,
where there's no terminal to `export` into), set them up in `secrets.sh` now, before enabling the
features that need them:
```bash
cp secrets.sh.example secrets.sh
chmod 600 secrets.sh
```
Edit `secrets.sh` and fill in whichever keys apply. Full detail (including a fallback option and
why `secrets.sh` and not `~/.bashrc`) in [Storing API Keys on the Device](api-keys.md).

Flickr needs one extra one-time step — a browser-based OAuth authorization — covered in
[Publishing to Flickr](publishing-flickr.md#one-time-setup); do this now while you're already in
the API-key mindset, since it also needs `FLICKR_API_KEY`/`FLICKR_API_SECRET` set first.

## 11. Turn on the AI-edit feature (optional)

Set `"ai_edit.enabled"`/`"ai_edit.input_method"` in `settings.json` — `"voice"` (hold-to-talk) or
`"keyboard"` (tap, pick a preset or type one). If using `"voice"` with the local Vosk provider,
confirm the model loads (step 5 covers installing it):
```bash
python -c "import vosk; vosk.Model('models/vosk-model-small-en-us-0.15'); print('Vosk model OK')"
```
Either input method also needs a working microphone — see
[Voice-Prompted AI Edits § Setup](voice-ai-edits.md#setup) for the `arecord` test command and full
detail on both input methods.

## 12. Turn on publishing destinations (optional)

For each destination you set up keys for in step 10, set its `"enabled"` and the rest of its block
under `"publish"` in `settings.json` — see [Publishing to Flickr](publishing-flickr.md#configuration)
and [Publishing to Bluesky](publishing-bsky.md#configuration) for the options each one takes.

## 13. Set up printing (optional)

Get a printer working with CUPS first — [Canon SELPHY CP400 + CUPS](printer-cups-setup.md) if
you're using that specific printer, otherwise get any printer showing up in `lpstat -p -d`. Then
set `"printing.printer"` in `settings.json` to its CUPS name (or leave it `null` to use whatever
CUPS' own default is). Turn on a watermark/date stamp on printed copies via the `"watermark"`/
`"datestamp"` blocks if wanted. Full detail: [Printing](printing.md).

## 14. [camera mode] Set up extras (optional)

* [Exposure Compensation](exposure-compensation.md) — the EV-/EV+ range/step, under `"exposure"`.
* [Shutter Remotes](shutter-remote.md) — Bluetooth, wired USB-serial, and/or GPIO button, any
  combination, under `"shutter_remote"`/`"serial_remote"`/`"gpio_remote"`.
* [Audio Output (Shutter Sound)](audio-output.md) — the click sound played on capture, under
  `"audio_output"`.

## 15. First run

```bash
python custard_cream_camera.py
```
See [Running the App](running-the-app.md) for what to expect on screen in each mode, and keyboard
shortcuts (`q` to quit, spacebar to shoot) available when launched from a terminal.

## 16. Set up launch-from-desktop-icon (optional, for a device with no keyboard)

Once step 15 works from a terminal, [run_custard_cream_camera.sh](../run_custard_cream_camera.sh)
and [custard-cream-camera.desktop](../custard-cream-camera.desktop) let the same thing launch by
double-clicking an icon instead. See [Running the App § From a Desktop Icon](running-the-app.md#from-a-desktop-icon)
for installing it and the file-manager quirks (executable bit, "untrusted" prompts) that trip this
up on a fresh clone.

## Done

At this point you have a working device. From here, the docs listed in the README's
[Reference](../README.md#reference) section cover each feature in more depth than this walkthrough
does — go there when you want to change how something already set up here behaves, or when
troubleshooting something specific.

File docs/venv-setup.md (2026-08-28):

# Setting Up the Python Virtual Environment on Raspberry Pi OS

This app always runs inside a Python virtual environment — everything below happens in a `venv`,
nothing is installed into the system Python. What you install depends on which `"mode"` (see
[Home Screen: Camera Mode vs FTP Mode](home-screen-modes.md)) this device will run in — a
camera-mode device needs the Pi's camera stack, an FTP-mode device doesn't need anything camera
-related at all. A `"camera_ftp"`-mode device needs the camera stack too — follow the **Camera
mode** instructions throughout this doc; `pyftpdlib` (the FTP receiver) is already in the common
`requirements.txt`, so no separate install step is needed for the FTP side.

If you run this app on more than one device (one in camera mode, one in FTP mode), each device gets
its own independent venv at its own clone of this repo — there's no environment shared between them.

## Why `picamera2` needs special handling (camera mode only)

Almost every dependency (`pillow`, `numpy`) is a normal PyPI package and installs fine
into any plain venv via `requirements.txt` — no apt packages needed for those.

`picamera2` is the one exception, and it's only needed in camera mode. It's built on top of
`libcamera`, which talks directly to the Pi's camera ISP and tuning files, and is not published as a
portable pip wheel — it has to be the OS build from `apt` so it matches your kernel and camera
stack. A plain (isolated) venv can't see that OS-installed package, so a camera-mode device creates
its venv with `--system-site-packages`: this lets the venv see the apt-installed
`picamera2`/`libcamera`, while every other package still installs normally and independently via
`pip`. An FTP-mode device skips all of this and uses a plain, fully-isolated venv instead.

`pycups` (used for [printing](printing.md)) is a normal PyPI package too, but unlike the others it's
a C extension that links against CUPS's own headers at install time, so `libcups2-dev` needs to
already be on the system before `pip install -r requirements.txt` gets to it — needed either way.

## Installing System Packages

**Camera mode** — install `picamera2` and its `libcamera` dependency, plus the CUPS headers
`pycups` needs to build (Raspberry Pi OS / Debian-like):

```bash
sudo apt update
sudo apt install -y \
	python3-picamera2 \
	python3-libcamera \
	python3-venv \
	libcups2-dev
```

**FTP mode** — no camera stack needed:

```bash
sudo apt update
sudo apt install -y python3-venv libcups2-dev
```

Either mode, if you use the `hdmi-desktop` display backend (the default, see
[Display Backends](display-backends.md)), you also need Tkinter, a system package rather than a pip
one:

```bash
sudo apt install python3-tk
```

## Creating the Virtual Environment

**Camera mode** — needs `--system-site-packages` (see above):

```bash
python3 -m venv --system-site-packages venv
```

**FTP mode** — a plain, fully-isolated venv is enough:

```bash
python3 -m venv venv
```

## Activating the Virtual Environment

```bash
source venv/bin/activate
```

The command prompt should change to show that the virtual environment is active:

```text
(venv) rob@raspberrypi:~/custard-cream-camera $
```

## Installing Python Dependencies

Install the common packages, needed in either mode:

```bash
python -m pip install --upgrade pip
python -m pip install -r requirements.txt
```

**Camera mode only** — also install `picamera2` itself, kept in a separate
[requirements-camera.txt](../requirements-camera.txt) rather than the common `requirements.txt`,
since it isn't safely installable on an FTP-only device with no `libcamera` OS package present:

```bash
python -m pip install -r requirements-camera.txt
```

**Only if `"ai_edit.input_method"` is `"voice"` and `"custard_cream.transcribe_provider"` is
`"vosk"`** (see [Voice-Prompted AI Edits](voice-ai-edits.md)) — install `vosk` itself, kept in its
own [requirements-vosk.txt](../requirements-vosk.txt) rather than the common `requirements.txt`,
since it's a real cost (see below) not worth paying on a device that never uses it — e.g. a
low-spec keyboard/preset-only image receiver:

```bash
python -m pip install -r requirements-vosk.txt
```

## Installing Vosk (Local Speech Recognition)

`vosk` (used for offline transcription in [Voice-Prompted AI Edits](voice-ai-edits.md)) is a normal PyPI package, installed via `requirements-vosk.txt` above — no apt package needed, either mode. Prebuilt wheels are published for 64-bit Raspberry Pi OS (aarch64); older 32-bit (armv7) installs may need to build from source — a Raspberry Pi Zero W 2 (a common choice for FTP mode) is aarch64-capable but ships 32-bit Raspberry Pi OS by default, so check which image you're running before assuming a prebuilt wheel is available.

Unlike the Python package, the **speech model itself is not installed by pip** — it's a separate download you place on disk yourself:

```bash
cd ~/custard-cream-camera
mkdir -p models
curl -LO https://alphacephei.com/vosk/models/vosk-model-small-en-us-0.15.zip
unzip vosk-model-small-en-us-0.15.zip -d models
rm vosk-model-small-en-us-0.15.zip
```

This should leave a `models/vosk-model-small-en-us-0.15/` folder, matching the default `"custard_cream.vosk.model_path"` in `settings.json` — adjust that setting if you download a different model or unzip it elsewhere. Larger/more accurate models are listed at [alphacephei.com/vosk/models](https://alphacephei.com/vosk/models); the vosk-small model (~40MB) is a deliberately lightweight default, useful if this device is a lower-powered Pi.

This model is loaded once at app startup (not lazily on first use), so a missing or misconfigured `model_path` will fail the whole app on launch while `"custard_cream.transcribe_provider"` is set to `"vosk"` (the default) — verify it loads before relying on it:

```bash
python -c "import vosk; vosk.Model('models/vosk-model-small-en-us-0.15'); print('Vosk model OK')"
```

## Verifying Camera Support (camera mode only)

To check that the virtual environment can access the Raspberry Pi camera libraries:

```bash
python -c "from picamera2 import Picamera2; print('Picamera2 OK')"
```

and:

```bash
python -c "import libcamera; print('libcamera OK')"
```

## Deactivating the Virtual Environment

When you have finished working:

```bash
deactivate
```

This returns you to the system Python environment.

## Recreating the Environment

If the environment becomes corrupted or you want to start again:

```bash
deactivate
rm -rf venv

python3 -m venv --system-site-packages venv   # or plain "venv" for an FTP-mode device
source venv/bin/activate
python -m pip install -r requirements.txt
python -m pip install -r requirements-camera.txt   # camera mode only
python -m pip install -r requirements-vosk.txt      # only if using voice input with the vosk provider
```

## Notes

* Do not commit the `venv` folder to Git.
* Add `venv/` to `.gitignore`.
* `requirements.txt`/`requirements-camera.txt`/`requirements-vosk.txt` should contain only packages installed via `pip`.
* Raspberry Pi OS packages such as Picamera2 should be installed using `apt`, not added to any requirements file.

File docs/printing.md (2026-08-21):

# Printing

The **Print** button (see [Home Screen: Camera Mode vs FTP Mode](home-screen-modes.md)) sends the currently displayed photo to CUPS via [pycups](https://github.com/OpenPrinting/pycups) — see the [Canon SELPHY CP400 setup](printer-cups-setup.md) for getting a printer configured. Submitting and watching the job runs on a background thread, the same way [publishing](../lib/publishers/) and [AI edits](voice-ai-edits.md) do, so the app stays responsive while it works. This whole flow (`prepare_print_copy()`/`run_print()`/`wait_for_print_job()`/...) lives in [custard_cream_camera.py](../custard_cream_camera.py).

If no `"printer"` is set under `"printing"` in [settings.json](../settings.json.example), the app falls back to CUPS's configured default destination — if neither exists, printing fails with "No printer configured" (check `lpstat -p -d` for the list of configured printers and current default, and `sudo lpadmin -d <printer-name>` to set one).

## Detecting a Failed Print

Submitting a job only confirms CUPS queued it, not that it actually came out — a paper jam or empty tray fails later, asynchronously. So after submitting, the app polls the job's status (`job-state`/`job-state-reasons`) via the same CUPS connection until it reaches a final state, and shows the result on screen:

* **Printed!** — the job completed.
* A specific reason (e.g. from `job-printer-state-message`, or the first `job-state-reasons` entry) — the job was canceled or aborted, most often by the printer itself (paper out, a jam).
* **Print taking longer than expected** — the job hadn't reached a final state after `"job_timeout_seconds"` (default `120`) under `"printing"` in settings.json; raise this if your printer is normally just slower than that.

Since real prints can take a minute or more on the CP400, this polling happens on the same background thread as the submission - see `run_print()`/`wait_for_print_job()` in `custard_cream_camera.py`.

## Recovering From a Stuck Queue

A print that fails outright (e.g. an empty paper tray) can leave CUPS with a disabled, rejecting queue for that printer — every print after it then just piles up in the spool instead of erroring, so nothing comes out even once the printer's fixed. To avoid that, before every print the app clears and re-enables the queue for whichever printer is configured (`reset_printer_queue()`, equivalent to running `cancel -a`, `cupsenable`, and `cupsaccept` on it), using the same CUPS connection as the job submission that follows.

Because this goes through pycups rather than shelling out, it doesn't need `sudo` — CUPS authorizes it directly against the caller's `lpadmin` group membership, the same membership set up in [Canon SELPHY CP400 setup](printer-cups-setup.md#add-your-user-to-the-printer-administration-group). If that account isn't in the group, this step fails, but only logs the failure rather than blocking the print attempt that follows.

## Print Testing

Set `"test_mode": true` under `"printing"` in [settings.json](../settings.json.example) to try out the print pipeline — watermark and date stamp included — without spending paper/ink: pressing **Print** saves the exact image that would have been sent to the printer into `"test_folder"` (default `print_tests/`, gitignored) instead of actually printing it. The console prints exactly where it was saved. Set back to `false` (the default) to resume printing for real.

## Watermark and Date Stamp

Prints can have a watermark logo and/or a date/time stamp composited on automatically — implemented in [lib/print_overlays.py](../lib/print_overlays.py). Both are applied only to the copy sent to the printer (via a temporary file); the original saved photo in `captures/` is never modified.

**Watermark** (`"watermark"` in [settings.json](../settings.json.example)):

```json
"watermark": {
    "enabled": true,
    "file": "assets/images/watermark.png",
    "horizontal_align": "right",
    "vertical_align": "bottom",
    "width_fraction": 0.2,
    "margin_fraction": 0.02
}
```

* `"file"` — path to a PNG, relative to the repo root. Transparent areas show the photo through, so the source PNG needs an alpha channel (both files under [assets/images/](../assets/images/) already have one).
* `"horizontal_align"`/`"vertical_align"` — which corner: `"left"`/`"right"` and `"top"`/`"bottom"`.
* `"width_fraction"` — how wide the watermark should be, as a fraction of the photo's width (aspect ratio is preserved, so this also determines its height).
* `"margin_fraction"` — gap from the edges, as a fraction of the photo's width/height.

**Date stamp** (`"datestamp"` in settings.json):

```json
"datestamp": {
    "enabled": true,
    "format": "%Y-%m-%d %H:%M",
    "horizontal_align": "left",
    "vertical_align": "bottom",
    "font_fraction": 0.035,
    "margin_fraction": 0.02,
    "text_colour": [255, 255, 255, 255],
    "background_colour": [0, 0, 0, 140]
}
```

* `"format"` — a [`strftime`](https://docs.python.org/3/library/time.html#time.strftime) format string. The stamp reflects the file's modification time - in camera mode that's when the photo was actually taken; in FTP mode it's the moment the file was saved into `captures/` after arriving over FTP, not when the camera actually took the shot (the camera's own EXIF capture time isn't read).
* `"font_fraction"` — text size as a fraction of the photo's height.
* `"text_colour"`/`"background_colour"` — `[R, G, B, A]`; the background box (drawn behind the text for legibility over busy photos) defaults to semi-transparent black.

Both default to the bottom corners (watermark bottom-right, date stamp bottom-left) so they don't overlap — adjust either independently if you'd rather they sit elsewhere. If a watermark/date stamp fails to apply for any reason (bad path, corrupt font, etc.), that step is skipped with a printed error rather than blocking the print entirely.

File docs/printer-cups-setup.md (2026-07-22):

# Using a Canon SELPHY CP400 with Raspberry Pi and CUPS

A good way to get cheap hard copy connect a Canon SELPHY CP400 dye-sublimation photo printer your a Raspberry Pi.

## Hardware Used

* Raspberry Pi (tested on Raspberry Pi 5)
* Canon SELPHY CP400
* Canon KP-36IP postcard media pack
* USB connection between printer and Pi

## Add Your User to the Printer Administration Group

Installations and printer management require membership of the `lpadmin` group. This is also needed at runtime: the app clears and re-enables the print queue before every print (see [Recovering From a Stuck Queue](printing.md#recovering-from-a-stuck-queue)), which requires the account running the app to be in this group.

```bash
sudo usermod -aG lpadmin $USER
```

Log out and back in after running this command.

Verify membership:

```bash
groups
```

You should see `lpadmin` in the list.

## Install CUPS

Install the CUPS printing system:

```bash
sudo apt update
sudo apt install cups
```

Enable and start CUPS:

```bash
sudo systemctl enable cups
sudo systemctl start cups
```

Check that it is running:

```bash
systemctl status cups
```

## Install Gutenprint

The Raspberry Pi package repository contains a Gutenprint package:

```bash
sudo apt install printer-driver-gutenprint
```

Unfortunately, the packaged version may contain a bug that prevents the CP400 from recognising postcard media correctly.

Typical error:

```text
Incorrect paper loaded (01 vs 11), aborting job!
```

If you encounter this error, build Gutenprint from source as described below.

## Building Gutenprint from Source

Install build dependencies:

```bash
sudo apt install \
    build-essential \
    libcups2-dev \
    libcupsimage2-dev \
    libusb-1.0-0-dev \
    libtiff-dev \
    libjpeg-dev \
    libpng-dev \
    gettext
```

Download and unpack Gutenprint:

```bash
wget https://downloads.sourceforge.net/project/gimp-print/gutenprint-5.3/5.3.3/gutenprint-5.3.3.tar.xz

tar xf gutenprint-5.3.3.tar.xz

cd gutenprint-5.3.3
```

Build and install:

```bash
./configure
make -j4
sudo make install
```

Restart CUPS:

```bash
sudo systemctl restart cups
```

## Discover the Printer

Connect the CP400 via USB and run:

```bash
lpinfo -v
```

Typical output:

```text
direct gutenprint53+usb://canon-cp400/NONE_UNKNOWN
```

Find the available driver:

```bash
lpinfo -m | grep -i cp400
```

Typical output:

```text
gutenprint.5.3://canon-cp400/expert Canon SELPHY CP400
```

## Create the Printer

Create the printer using the discovered URI and driver:

```bash
sudo lpadmin \
    -p SELPHY_CP400 \
    -E \
    -v "gutenprint53+usb://canon-cp400/NONE_UNKNOWN" \
    -m "gutenprint.5.3://canon-cp400/expert"
```

Enable the printer:

```bash
sudo cupsenable SELPHY_CP400
sudo cupsaccept SELPHY_CP400
```

Make it the default printer:

```bash
sudo lpadmin -d SELPHY_CP400
```

## Verify Page Size

Check available page sizes:

```bash
lpoptions -p SELPHY_CP400 -l | grep PageSize
```

Expected output:

```text
PageSize/Media Size: *Postcard w253h337 w155h244 w283h566
```

The asterisk indicates the current default.

The CP400 should normally use:

```text
Postcard
```

when printing KP-36IP media.

## Paper Size Problems

If printing fails with:

```text
Incorrect paper loaded (01 vs 11), aborting job!
```

check the following:

### 1. Correct Media Pack

Use matching Canon paper and ribbon cartridges.

Example:

```text
KP-36IP
```

### 2. Correct Cassette

Ensure the cassette is marked:

```text
Postcard
```

and matches the media pack.

### 3. Correct Driver Page Size

Verify:

```bash
lpoptions -p SELPHY_CP400 -l | grep PageSize
```

shows:

```text
*Postcard
```

### 4. Rebuild Gutenprint

If all settings are correct and the error persists, rebuild Gutenprint from source.

In testing, rebuilding Gutenprint resolved the "01 vs 11" media mismatch problem.

## Print a Test Page

Print the CUPS test page:

```bash
lp -d SELPHY_CP400 /usr/share/cups/data/testprint
```

If successful, the printer should begin feeding paper and printing immediately.

## Useful Commands

Show printer status:

```bash
lpstat -p -d
```

Show printer options:

```bash
lpoptions -p SELPHY_CP400
```

Show printer configuration:

```bash
lpstat -l -p SELPHY_CP400
```

Show recent CUPS errors:

```bash
tail -50 /var/log/cups/error_log
```

Both commands should complete without errors. Enable the camera stack (libcamera) in `raspi-config` if needed.

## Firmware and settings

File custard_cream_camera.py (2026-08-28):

import io
import json
import queue
import select
import shutil
import subprocess
import sys
import tempfile
import termios
import time
import tty
from pathlib import Path
from threading import Event, Thread

import cups
import qrcode
from PIL import Image, ImageDraw, ImageFont, ImageOps

# displays/publishers/transcription packages and NanoBananaClient.py/print_overlays.py/
# ftp_server.py all live in ./lib, next to this file.
sys.path.insert(0, str(Path(__file__).resolve().parent / "lib"))

from displays import Button, colours, create_display
from NanoBananaClient import CustardCreamClient
from print_overlays import apply_datestamp, apply_watermark
from publishers import available_publishers, create_publisher, publisher_label
from transcription import create_transcriber

SETTINGS_PATH = Path(__file__).parent / "settings.json"
VERSION_PATH = Path(__file__).parent / "VERSION"
GITHUB_URL = "https://github.com/CrazyRobMiles/custard-cream-camera"

# IPP job-state values (RFC 8011 SS5.3.7) - pycups surfaces the raw int rather than named
# constants, so the ones this code checks for are spelled out here instead.
CUPS_JOB_STATE_CANCELED = 7
CUPS_JOB_STATE_ABORTED = 8
CUPS_JOB_STATE_COMPLETED = 9

# How often wait_for_print_job() refreshes the on-screen status from `lpstat -t` while a print
# is in flight - frequent enough to catch a paper-out/jam message promptly, without spawning a
# subprocess on every 1s job-state poll.
LPSTAT_POLL_SECONDS = 5


def load_settings():
    with open(SETTINGS_PATH) as f:
        return json.load(f)


def load_version():
    try:
        return VERSION_PATH.read_text().strip()
    except OSError:
        return "unknown"


def _largest_size_with_aspect(max_width, max_height, aspect):
    """The largest (width, height) with the given width/height aspect ratio that fits within
    max_width x max_height, rounded down to even dimensions (some capture formats require it).
    Used to size both the still capture and the live preview from the printed aspect ratio
    (settings["printing"]) rather than the sensor's native aspect or the screen's own aspect, so
    the framing seen live always matches what actually gets printed - see self.print_aspect.
    """
    if max_width / max_height > aspect:
        height = max_height
        width = height * aspect
    else:
        width = max_width
        height = width / aspect
    return int(width) // 2 * 2, int(height) // 2 * 2


# ------------------------------------------------------------
# Keyboard handling (non-blocking)
# ------------------------------------------------------------

class Keyboard:
    def __init__(self):
        # Launched from a desktop icon (Terminal=false), stdin isn't a real
        # TTY, so termios setup would raise - keyboard shortcuts just aren't
        # available in that case, since touch/the shutter remote cover it.
        self.enabled = sys.stdin.isatty()
        if self.enabled:
            self.fd = sys.stdin.fileno()
            self.old = termios.tcgetattr(self.fd)
            tty.setcbreak(self.fd)

    def get_key(self):
        if not self.enabled:
            return None
        if select.select([sys.stdin], [], [], 0)[0]:
            return sys.stdin.read(1)
        return None

    def close(self):
        if self.enabled:
            termios.tcsetattr(self.fd, termios.TCSADRAIN, self.old)


class CustardCreamCamera:
    """Home screen(s) picked by settings.json's "mode":

    - "camera" (self.has_camera=True, self.has_ftp=False): a live Picamera2 viewfinder with
      Capture/Play modes.
    - "ftp" (self.has_camera=False, self.has_ftp=True): no camera - photos arrive over FTP (see
      lib/ftp_server.py) and the app is always in Play/play_grid, starting on a "waiting for
      photos" placeholder.
    - "camera_ftp" (both True): a live Picamera2 viewfinder like camera mode, plus the FTP
      receiver running in the background - an FTP upload interrupts Capture/Play the same way it
      does in "ftp" mode, landing back in Capture mode is unaffected.

    Either way, reviewing/printing/publishing/voice-editing photos already in save_dir - the
    "review station" methods below (Play mode, printing, publishing, the voice/keyboard AI-edit
    flow) - is exactly the same regardless of mode; only the few methods under "Camera-mode hooks"
    branch on self.has_camera, and the FTP receiver's own setup/polling/teardown branch on
    self.has_ftp.
    """

    # Button colour per destination, shown in the publish menu - falls back to grey for any
    # publisher type not listed here.
    PUBLISH_MENU_COLOURS = {
        "flickr": colours.PUBLISH,
        "bsky": colours.BSKY,
        "custard_cream_server": colours.CUSTARD_CREAM_SERVER,
    }

    def __init__(self):
        settings = load_settings()
        self.settings = settings
        self.app_dir = Path(__file__).resolve().parent
        self.version = load_version()
        mode_setting = settings.get("mode", "camera")
        self.has_camera = mode_setting in ("camera", "camera_ftp")
        self.has_ftp = mode_setting in ("ftp", "camera_ftp")

        # Read early - both the still and live-preview capture sizes below are derived from this
        # (not the sensor's native aspect, not the screen's own aspect), so what's framed live
        # always matches what actually comes out of the printer. Paper size is configurable
        # rather than assuming this printer's 6x4in postcard size forever.
        printing_settings = settings.get("printing", {})
        self.printing_settings = printing_settings
        self.print_aspect = (
            printing_settings.get("paper_width_inches", 6) / printing_settings.get("paper_height_inches", 4)
        )

        # Load three font sizes
        self.small_font = ImageFont.truetype(
            "/usr/share/fonts/truetype/dejavu/DejaVuSans.ttf", 16
        )

        self.medium_font = ImageFont.truetype(
            "/usr/share/fonts/truetype/dejavu/DejaVuSans.ttf", 32
        )

        self.large_font = ImageFont.truetype(
            "/usr/share/fonts/truetype/dejavu/DejaVuSans.ttf", 48
        )

        # The Play menu's four-across row (and other narrow multi-button rows) need a smaller
        # legend than the wider buttons that also use medium_font - this doesn't affect them.
        self.play_button_font = ImageFont.truetype(
            "/usr/share/fonts/truetype/dejavu/DejaVuSans.ttf", 26
        )
        self.phrase_font = ImageFont.truetype(
            "/usr/share/fonts/truetype/dejavu/DejaVuSans.ttf", 18
        )

        # Created before the preview config below, since the preview capture size follows
        # self.screen.WIDTH/HEIGHT (the logical canvas size, configurable via settings["display"]
        # - see displays/__init__.py) rather than a hardcoded resolution.
        self.screen = create_display(settings)

        self.audio_output_settings = settings.get("audio_output", {})

        # AI-edit input: "voice" (hold-to-talk + a transcriber) or "keyboard" (tap, pick a preset
        # prompt or type a custom one) - or disabled entirely. Read early since it decides what
        # the play menu's Speak/AI Edit button looks like (_build_play_menu() below) and whether
        # a transcriber is created at all further down.
        ai_edit_settings = settings.get("ai_edit", {})
        self.ai_edit_settings = ai_edit_settings
        self.ai_edit_enabled = ai_edit_settings.get("enabled", True)
        self.ai_input_method = ai_edit_settings.get("input_method", "voice")

        self.kbd = Keyboard()

        button_y = self.screen.HEIGHT - 50
        arrow_y = 40 + (self.screen.HEIGHT - 40 - 50 - 100) // 2
        # Height of the area actually visible above the bottom Capture/Play button row - the
        # live preview is fit within this area (see preview_config below) rather than the full
        # screen height, so it's never drawn full-screen only to have its bottom strip hidden
        # behind the opaque button bar.
        self.content_height = button_y

        if self.has_camera:
            # picamera2/libcamera and the shutter-remote modules are only importable on a device
            # with the Pi camera stack/hardware actually installed - never attempted in FTP mode.
            from libcamera import Transform
            from picamera2 import Picamera2
            from gpio_shutter_remote import GpioShutterRemote
            from serial_shutter_remote import SerialShutterRemote
            from shutter_remote import ShutterRemote

            self.picam2 = Picamera2()

            # Corrects for the sensor being mounted rotated 180 degrees in this build - flip both
            # axes rather than rotating every captured frame in software afterward. Viewfinder and
            # capture are transformed independently (each falling back to the top-level hflip/vflip
            # when not overridden) so a traditional reflex-style viewfinder - e.g. mirrored left-
            # right relative to what's actually saved - can be set up without affecting stills.
            camera_settings = settings.get("camera", {})
            base_hflip = camera_settings.get("hflip", False)
            base_vflip = camera_settings.get("vflip", False)
            viewfinder_settings = camera_settings.get("viewfinder", {})
            capture_settings = camera_settings.get("capture", {})

            # Auto-switch to Play mode after Capture mode sits idle for a while - Capture mode
            # keeps the sensor streaming continuously (see enter_play()/enter_capture() below),
            # which is the expensive state to be left in unattended. Off by default since it
            # changes on-screen behavior, not just performance.
            idle_timeout_settings = camera_settings.get("idle_timeout", {})
            self.idle_timeout_enabled = idle_timeout_settings.get("enabled", False)
            self.idle_timeout_seconds = idle_timeout_settings.get("seconds", 60)
            self.last_capture_activity = time.monotonic()
            viewfinder_transform = Transform(
                hflip=viewfinder_settings.get("hflip", base_hflip),
                vflip=viewfinder_settings.get("vflip", base_vflip),
            )
            capture_transform = Transform(
                hflip=capture_settings.get("hflip", base_hflip),
                vflip=capture_settings.get("vflip", base_vflip),
            )

            # An explicit optical crop to self.print_aspect, centered in the sensor's full pixel
            # array - deliberately not just requesting an output "size" of that aspect ratio and
            # trusting the ISP to crop for us: without ScalerCrop, a main-stream size narrower
            # than the sensor mode's own aspect ratio gets the whole field of view non-uniformly
            # squeezed to fit instead of cropped, distorting the image (visible on stills; the
            # live preview only "looked fine" because the same squeeze is subtler on a small,
            # moving image). Reading sensor_resolution rather than hardcoding it also means this
            # keeps working if the camera module itself changes, not just the printer.
            sensor_w, sensor_h = self.picam2.sensor_resolution
            crop_w, crop_h = _largest_size_with_aspect(sensor_w, sensor_h, self.print_aspect)
            self.print_crop = ((sensor_w - crop_w) // 2, (sensor_h - crop_h) // 2, crop_w, crop_h)

            # Left to its own defaults, Picamera2 picks whichever sensor mode can supply the
            # requested preview main-stream size - for a small preview resolution that's often a
            # genuinely cropped/windowed readout mode, not a full-field-of-view binned one,
            # narrowing the preview's field of view relative to stills (which always use the
            # full-resolution, and therefore full-FOV, mode). That mismatch shows up as the live
            # viewfinder looking "zoomed in" next to what's actually printed. Pinning the preview
            # to the smallest mode that still covers the full sensor FOV keeps the two in sync -
            # still preview-sized, just not cropped. crop_limits gives each mode's available crop
            # rectangle in native sensor coordinates, so the mode(s) tied for the largest one are
            # exactly the full-FOV modes.
            sensor_modes = self.picam2.sensor_modes
            max_fov_area = max(m["crop_limits"][2] * m["crop_limits"][3] for m in sensor_modes)
            full_fov_modes = [m for m in sensor_modes if m["crop_limits"][2] * m["crop_limits"][3] == max_fov_area]
            preview_sensor_mode = min(full_fov_modes, key=lambda m: m["size"][0] * m["size"][1])

            # Both capture sizes are fit within the largest box available - the full crop for
            # stills, the on-screen content area for the live preview - and since the crop is
            # already at print_aspect, the ISP's scale down to either output size is always
            # uniform. _place_in_frame() handles centering/letterboxing either one on screen.
            # Capping the preview frame rate matters on low-powered hardware: each frame drives
            # a full copy/overlay/letterbox/encode/Tk-swap in process_frame(), and left uncapped
            # this runs at the sensor mode's native rate (often 30-60fps+) - far faster than the
            # on-screen viewfinder needs, and enough to starve Tkinter's event loop of time to
            # process touch input, which is what makes buttons feel laggy/unresponsive. Setting
            # it to None disables the cap. Trade-off: this also caps the longest exposure time
            # AE/EV+ can reach (frame duration must be >= exposure time), so a very low preview_fps
            # could clip EV+ headroom in dim scenes - 15fps leaves ~66ms, well above typical
            # metered exposure times indoors/outdoors.
            preview_controls = {}
            preview_fps = camera_settings.get("preview_fps", 15)
            if preview_fps:
                frame_duration_us = int(1_000_000 / preview_fps)
                preview_controls["FrameDurationLimits"] = (frame_duration_us, frame_duration_us)

            self.preview_config = self.picam2.create_preview_configuration(
                main={"size": _largest_size_with_aspect(self.screen.WIDTH, self.content_height, self.print_aspect), "format": "BGR888"},
                transform=viewfinder_transform,
                controls=preview_controls,
                sensor={"output_size": preview_sensor_mode["size"], "bit_depth": preview_sensor_mode["bit_depth"]},
            )

            self.still_config = self.picam2.create_still_configuration(
                main={"size": (crop_w, crop_h), "format": "BGR888"},
                transform=capture_transform,
                controls={"ScalerCrop": self.print_crop},
            )

            self.picam2.configure(self.preview_config)

            # print_crop's coordinates were computed against sensor_resolution, the full-FOV
            # mode picked above should honour them unclamped - but re-deriving the crop from
            # this mode's own bounds (queryable only now, after configure(), once the mode is
            # actually active) rather than assuming they match sensor_resolution exactly is a
            # cheap belt-and-braces: if the two ever disagree, libcamera would otherwise silently
            # clamp print_crop to whatever's valid, which can leave it at something other than
            # print_aspect - and the ISP would then stretch that wrong-aspect crop to fill the
            # still-print_aspect main stream size, distorting the live preview specifically (this
            # is what previously showed up as the viewfinder looking vertically stretched while
            # Play-mode/printed photos looked right).
            _, preview_crop_bounds, _ = self.picam2.camera_controls["ScalerCrop"]
            mode_x, mode_y, mode_w, mode_h = preview_crop_bounds
            preview_crop_w, preview_crop_h = _largest_size_with_aspect(mode_w, mode_h, self.print_aspect)
            preview_crop = (
                mode_x + (mode_w - preview_crop_w) // 2,
                mode_y + (mode_h - preview_crop_h) // 2,
                preview_crop_w,
                preview_crop_h,
            )
            self.picam2.set_controls({"ScalerCrop": preview_crop})

            self.picam2.start()
            # Tracks whether the sensor is actually streaming - Play mode stops it (see
            # enter_play() below), since the live feed is never shown there, and this is what
            # enter_capture()/process_frame() check to know whether to restart it and resume
            # pumping capture_request()s.
            self.camera_streaming = True

            # Exposure compensation via the on-screen +/- buttons, for backlit subjects etc. The
            # libcamera "ExposureValue" control (the "correct" way to bias AE without disabling it)
            # turned out to be a no-op on this camera/tuning stack - confirmed by watching the
            # on-screen shutter-speed readout while pressing the buttons and seeing it never move -
            # so instead this snapshots the AE-computed ExposureTime/AnalogueGain as a baseline the
            # moment EV moves off zero (see exposure_baseline below) and explicitly scales
            # ExposureTime by 2**ev from that baseline, handing control back to AE at EV 0.
            exposure_settings = settings.get("exposure", {})
            self.ev_step = exposure_settings.get("step", 0.5)
            self.ev_min = exposure_settings.get("min", -2.0)
            self.ev_max = exposure_settings.get("max", 2.0)
            self.exposure_value = exposure_settings.get("default", 0.0)
            # (exposure_time_us, analogue_gain) captured from AE right as EV last moved off zero -
            # every subsequent adjustment scales from this fixed point rather than the live reading,
            # since once AE is disabled the live reading is just our own last override, not a fresh
            # measurement - reading from it again would compound drift on repeated presses instead
            # of giving a clean, repeatable +/- N stops from where AE actually metered the scene.
            self.exposure_baseline = None

            self.frame_ready = Event()
            self.request_next_frame()

            comp_button_width = 80
            comp_button_height = 80

            # Capture mode: live viewfinder, take a photo or switch to Play mode to review/act on
            # existing ones. There's no on-screen quit button any more - use keyboard 'q', or
            # Escape/window-close on the  MI backends.
            self.capture_menu = (
                *self._row_of_buttons(button_y, 50, (
                    ("Click", self.medium_font, colours.BUTTON_TEXT, colours.PRIMARY, None, self.save_image),
                    ("Play", self.medium_font, colours.BUTTON_TEXT, colours.PLAY, None, self.enter_play),
                )),
                # Exposure compensation - tucked into the top corners since the bottom row is full.
                Button(0, 0, comp_button_width, comp_button_height, "EV-", self.small_font, colours.BUTTON_TEXT, colours.UTILITY, None, lambda: self.adjust_exposure(-self.ev_step)),
                Button(self.screen.WIDTH - comp_button_width, 0, comp_button_width, comp_button_height, "EV+", self.small_font, colours.BUTTON_TEXT, colours.UTILITY, None, lambda: self.adjust_exposure(self.ev_step)),
            )

            self.screen.set_buttons(self.capture_menu)

        # Play mode: reviews/acts on captures/ directly - Print/Speak or AI Edit/Publish always
        # target whatever's currently selected (self.play_index), no separate "choose, then act"
        # step. Left/Right step through images one at a time; Page opens a 3x3 grid to jump
        # further. Built regardless of mode - _build_play_menu() itself only adds a "Capture"
        # button when self.has_camera is set, so a camera-less "ftp" mode gets none.
        self.play_menu = self._build_play_menu(button_y, arrow_y)

        self.save_dir = Path("captures")
        self.save_dir.mkdir(exist_ok=True)

        self.printer_name = printing_settings.get("printer")
        self.print_test_mode = printing_settings.get("test_mode", False)
        self.print_test_dir = Path(printing_settings.get("test_folder", "print_tests"))
        if self.print_test_mode:
            self.print_test_dir.mkdir(exist_ok=True)

        # Printing ("Print" button) - printFile() only confirms the job was queued with CUPS,
        # not that it actually came out (paper jams/empty trays fail later, asynchronously), so
        # the real submit-and-watch work runs on a background thread the same way publish/AI
        # edit do, for the same reason (network/hardware I/O shouldn't block the viewfinder).
        self.print_pending = False
        self.print_done = Event()
        self.print_result = None
        # Set periodically by wait_for_print_job() from `lpstat -t` output while a print is in
        # flight, so the on-screen "Printing..." banner can show real diagnostic text (paper
        # out, offline, etc.) instead of a static placeholder - print_status_ready forces a
        # redraw the same way ai_status_ready does for the AI edit progress text.
        self.print_status_text = None
        self.print_status_ready = Event()

        self.watermark_settings = settings.get("watermark", {})
        self.datestamp_settings = settings.get("datestamp", {})

        self.finder = None
        self.last_metadata = None
        self.img = None
        self.running = None
        self.save_file_name = None
        self.last_photo_path = None
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

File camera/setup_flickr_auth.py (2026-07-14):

"""One-time interactive Flickr authorization.

Run this manually from a terminal - not part of the main camera app - to authorize custard_cream_camera.py
to publish to your Flickr account. It opens a 3-legged OAuth 1.0a flow: you visit a URL in any
browser (doesn't have to be on the Pi), approve the app, and paste back the verification code
Flickr gives you. The resulting access token is cached locally, so this only needs to be done
once - after that, the Publish button in custard_cream_camera.py works without any further browser step.

Usage:
    export FLICKR_API_KEY=...
    export FLICKR_API_SECRET=...
    python setup_flickr_auth.py
"""
import os
import sys

import flickrapi

API_KEY_ENV = "FLICKR_API_KEY"
API_SECRET_ENV = "FLICKR_API_SECRET"


def main():
    api_key = os.environ.get(API_KEY_ENV)
    api_secret = os.environ.get(API_SECRET_ENV)
    if not api_key or not api_secret:
        print(
            f"Set {API_KEY_ENV} and {API_SECRET_ENV} first - get them from "
            "https://www.flickr.com/services/apps/create/"
        )
        sys.exit(1)

    flickr = flickrapi.FlickrAPI(api_key, api_secret, format="parsed-json")

    if flickr.token_valid(perms="write"):
        print("Already authorized with write access - nothing to do.")
        return

    flickr.get_request_token(oauth_callback="oob")
    authorize_url = flickr.auth_url(perms="write")
    print(f"Open this URL in a browser and authorize the app:\n\n{authorize_url}\n")
    verifier = input("Paste the verification code Flickr gives you here: ").strip()
    flickr.get_access_token(verifier)
    print("Authorized - the access token is now cached. custard_cream_camera.py can publish to Flickr now.")


if __name__ == "__main__":
    main()

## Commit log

2026-06-18 working camera capture
2026-06-18 First button framework
2026-06-19 Touch buttons working
2026-06-26 Tidied up and moved buttons
2026-07-10 Added printer, nanobanana and bluetooth remote
2026-07-10 added printer, nanobanana and shutter_remote
2026-07-10 Added printer setting
2026-07-10 Fixed inverted camera display
    [magic_camera.py]
2026-07-12 Renamed custard cream camera
2026-07-12 renamed to custard cream camera
2026-07-14 Rename magic_camera app to custard_cream_camera, custard_cream module to NanoBananaClient
    Aligns the app's file/class/window names with the custard-cream-camera repo name, and disambiguates the Gemini/"Nano Banana" client module from the app entry point.
2026-07-14 Fix crash when launched without a controlling terminal
    Keyboard.__init__ called termios.tcgetattr(stdin) unconditionally, which
    raises when stdin isn't a real TTY - exactly the case when launched from
    the desktop icon (Terminal=false), crashing the app before it could show
    anything. Keyboard shortcuts are just a terminal convenience (touch/the
    shutter remote are the primary controls), so skip termios setup when
    stdin isn't a TTY instead of crashing.
    [custard_cream_camera.py]
2026-07-14 Add a Stop button to the play menu
    Launching from the desktop icon has no keyboard or window chrome to quit
    with, so there was previously no way to exit the app cleanly in that
    context short of killing the process.
    [custard_cream_camera.py]
2026-07-14 Add API key setup guide with gitignored secrets.sh; note USB touch power issue
    - run_custard_cream_camera.sh sources an optional secrets.sh (gitignored) for
    GOOGLE_API_KEY/FLICKR_API_KEY/FLICKR_API_SECRET, avoiding the risk of a real
    key ending up in a tracked file
    - docs/api-keys.md consolidates the practical setup guidance, replacing
    duplicated/stale instructions in voice-ai-edits.md and publishing-flickr.md
    - docs/display-backends.md: touch dropping out when a USB keyboard/mouse is
    plugged in is usually a USB power budget issue, not a driver bug
2026-07-14 Fix Speak misfiring after Play tap; log audio capture failures; shrink Play-menu button font
    The Play-mode Speak button sits at the same screen coordinates the
    Capture-mode Play button occupies, so a touch-driver bounce right after
    tapping Play could land on Speak in the new menu and start/stop a
    recording that was never meant to happen. ButtonPanel now ignores
    touch input for a short window after any menu swap.
    Also surface arecord's stderr and exit status when AudioRecorder.stop()
    comes back empty, so a real device error can be told apart from a
    too-quick tap, and reduce the Play menu's four narrow buttons to a
    smaller font that fits them better.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
    [custard_cream_camera.py]
2026-07-14 Document stray keyring dialog as cause of clicks silently not registering
    Update the "touch stops working" doc entry: it was diagnosed as a
    leftover modal keyring/password dialog from the Flickr OAuth setup
    step eating clicks, not a USB power issue as previously documented.
    Cross-link from the Flickr publishing doc so the setup step points
    back at the symptom.
2026-07-15 Add local Vosk transcription as a configurable Speak-button backend
    Speak-button transcription is now pluggable (custard_cream.transcribe_provider),
    mirroring the existing publishers/displays plugin pattern. Vosk runs locally on
    the Pi with no network round-trip and streams live partial transcripts to the
    screen while the button is held; Gemini remains available as the cloud
    alternative with the original static "Recording..." banner. Image editing stays
    on Gemini either way.
2026-07-15 Add camera photo and rewrite README intro
2026-07-15 Disable print test mode to send jobs to the real printer
2026-07-15 Let all publish destinations run at once with an enable/menu picker
    Publish now opens a per-destination menu (Flickr/Bluesky/Custard Cream
    Server) instead of a single settings["publish"]["type"] choice, skips
    straight to the only destination if just one is enabled, and names the
    destination in the success/failure message.
    [custard_cream_camera.py]
2026-07-15 Add a per-publisher button_text and shrink the server phrase text
    Publish-menu buttons are only 110px wide, too narrow for full names like
    "Custard Cream Server" - each publisher class now exposes its own short
    button_text (Flickr/Bsky/CC Server) for the menu, separate from the full
    name still used in "Published to ..." messages. Also drops the three-word
    phrase shown after a custard-cream-server upload down to the smaller
    play-menu button font, which was overflowing at medium_font size.
    [custard_cream_camera.py]
2026-07-21 Fixed font size for publish, increased delay and filtered :3001 from the qr code url
2026-07-22 Added printer control using pycups
2026-07-24 improved print diagnostic display
2026-07-26 fixed publish completion display
    [custard_cream_camera.py]
2026-07-31 Flatten camera/ and host/ into one settings-driven app
    The two apps already shared nearly everything through lib/; the FTP receiver
    is now treated as just another way photos arrive, picked by settings.json's
    "mode" key ("camera" or "ftp") instead of by which folder you're in. This
    also removes the class of bug from a stale .desktop/venv path left over
    after a prior folder move, since there's only one layout to keep in sync now.
    - Merge camera/custard_cream_camera.py + host/custard_cream_camera_host.py
    into one custard_cream_camera.py; hardware imports (picamera2/libcamera/
    shutter remotes/ftp_server) are lazy and mode-gated so an FTP-only device
    never needs the camera stack installed.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
    [custard_cream_camera.py, serial_shutter_remote.py, setup_flickr_auth.py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]
2026-07-31 improved button release detection
2026-07-31 fixed button action
2026-08-01 Improved image scaling and buttons
2026-08-01 Use ScalerCrop for print-aspect capture instead of relying on ISP scaling
    Requesting a main-stream size narrower than the sensor mode's aspect ratio
    without ScalerCrop let the ISP non-uniformly squeeze the full field of view
    to fit, distorting stills (subtle enough on the live preview to go unnoticed).
    Crop explicitly to print_aspect, centered in the sensor's full pixel array,
    so both preview and still scale down uniformly from an already-correct crop.
    [custard_cream_camera.py]
2026-08-02 Added non-voice AI edit for low power ftp version.
2026-08-03 improved button performance
2026-08-03 Fixed buttons and added separate viewfinder transformations
    [custard_cream_camera.py]
2026-08-14 Fixed remote shutter shutdown bug and resized exposure comp buttons
    [custard_cream_camera.py, serial_shutter_remote.py]
2026-08-14 Increased the size of Stop, Page and exposure compensation buttons.
2026-08-17 Add startup version splash and 3D-printed case STL files
    Shows the app version and GitHub URL on a splash screen for 2s at
    launch, and adds the case/ STL files with a README section describing
    how the pieces group into Controller/Battery/Printer/Handle/Paper.
    [BatteryBase.stl, BatteryLidLeft.stl, BatteryLidRight.stl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]
2026-08-17 Fixed viewfinder image stretch.
    [custard_cream_camera.py]
2026-08-17 Fixed viewfinder aspect ratio bug.
    [custard_cream_camera.py]
2026-08-19 added wired shutter release
    [custardcream web address.3mf, sign.3mf, viewfinder.stl]
2026-08-19 Fixed code missing frame_ready event
    [custard_cream_camera.py]
2026-08-20 Disabled camera capture when in the play menus.
2026-08-21 fixed sticking ftp splash screen
    [custard_cream_camera.py]
